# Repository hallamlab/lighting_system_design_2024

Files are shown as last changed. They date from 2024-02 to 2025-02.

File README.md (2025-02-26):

# An Automated High-Throughput Lighting System for Screening Photosynthetic Microorganisms in Plate-Based Formats

## Authors
Avery J. C. Noonan<sup>1,4,7</sup>, Paula M. N. Cameron<sup>2,4</sup>, Kalen Dofher<sup>2,4</sup>, Nannaphat Sukkasam<sup>2,4,5</sup>, Tony Liu<sup>3,4</sup>, Lucas Rönn<sup>2</sup>, Tanakarn Monshupanee<sup>5</sup>, and Steven J. Hallam<sup>1,2,3,4,6,7*</sup>

## Abstract
The capacity of photosynthetic microorganisms to fix carbon dioxide into biomass positions them as promising cell factories for industrial bioproduction with reduced environmental impact. However, limitations in screening throughput hinder the identification of enzymes, strains, and growth conditions needed to realize this potential. Here we present a microplate-based high-throughput cultivation system that can be integrated into existing automation infrastructure and supports growth of both prokaryotic and eukaryotic photosynthetic microorganisms. In one application, we optimize BG-11 medium compositions for *Synechococcus elongatus* UTEX 2973, *Chlamydomonas reinhardtii* UTEX 90, and *Nostoc hatei* CUBC1040, resulting in growth rate increases of 38.4% to 61.6%. In another application, we identify small molecules that influence growth rates in *Synechococcus elongatus* UTEX 2973, including candidate compounds for growth rate increase and dozens that prevent growth. The sensitivity, throughput, and extensibility of this system support screening, strain isolation, and growth optimization needed for the development of photosynthetic microbial cell factories.

---

## Repository Contents
The following table shows the contents of the repository and a brief description of each file:

| File | Topic | Directory | Description |
|---|---|---|---|
| **Noonan_HTP_lighting_system_figures.Rmd** | RMarkdown | . | RMarkdown generating all data figures |
| **Noonan_BG11-RSM_JMP_data_processing.Rmd** | RMarkdown | . | RMarkdown for RSM data reformatting for input into JMP |
| **PHERAstar_2x2_data_processing.py** | Python | . | Script for processing PHERAstar 2x2 data |
| **PHERAstar_standard_data_processing.py** | Python | . | Script for processing standard PHERAstar data |
| **varioskan_data_parsing.py** | Python | . | Script for parsing Varioskan data |
| **LED_driver.ino** | Arduino | . | Arduino script for controlling LED intensity |
| **parts-list.csv** | System | system-design/ | Parts list |
| **2973_plate-type_growth_data.csv** | Design / Validation | data/system-design/ | Culture OD data |
| **2973_seal_growth_data.csv** | Design / Validation | data/system-design/ | Culture OD data |
| **2973_spectrum_growth_data.csv** | Design / Validation | data/system-design/ | Culture OD data |
| **photodiode_array_data.csv** | Design / Validation | data/system-design/ | Photodiode data |
| **sensor_array_data.csv** | Design / Validation | data/system-design/ | Photodiode data |
| **layout_info.csv** | Design / Validation | data/system-design/ | Plate layout info |
| **echo_evaporation_data.csv** | Design / Validation | data/system-design/ | Evaporation data |
| **2973_BG11_growth_data.csv** | Primary Use-Cases | data/use-cases/primary/ | Culture OD data |
| **2973_BG11_plate_layout.csv** | Primary Use-Cases | data/use-cases/primary/ | Plate layout info |
| **2973_BG11_plate_metadata.csv** | Primary Use-Cases | data/use-cases/primary/ | Culture metadata |
| **antibiotics_growth_data.csv** | Primary Use-Cases | data/use-cases/primary/ | Culture OD data |
| **antiobiotics_plate_layout.csv** | Primary Use-Cases | data/use-cases/primary/ | Plate layout info |
| **antiobiotics_plate_metadata.csv** | Primary Use-Cases | data/use-cases/primary/ | Culture metadata |
| **layout_info.csv** | Primary Use-Cases | data/use-cases/primary/ | Plate layout info |
| **BG11_JMP_layout.csv** | BG-11 RSM | data/use-cases/BG11-RSM/ | Plate layout info |
| **BG11_opt_OD_data.csv** | BG-11 RSM | data/use-cases/BG11-RSM/ | Culture OD data |
| **flask_biomass_data_100uM.csv** | BG-11 RSM | data/use-cases/BG11-RSM/ | Culture biomass data |
| **bioactive_library_info.csv** | Bioactive Screen | data/use-cases/bioactive-screening/ | Screening library information |
| **bioactive_screen1_OD_data.csv** | Bioactive Screen | data/use-cases/bioactive-screening/ | Culture OD data |
| **bioactive_round2_OD_data.csv** | Bioactive Screen | data/use-cases/bioactive-screening/ | Culture OD data |
| **bioactive_screen_round2_hit_compound_info.csv** | Bioactive Screen | data/use-cases/bioactive-screening/ | Compound metadata |
| **bioactive_screen_round3_layout.csv** | Bioactive Screen | data/use-cases/bioactive-screening/ | Plate layout info |
| **bioactive_screen_round3_OD_data.csv** | Bioactive Screen | data/use-cases/bioactive-screening/ | Culture OD data |
| **bioactive_gradient_data.csv** | Bioactive Screen | data/use-cases/bioactive-screening/ | Culture OD data |
| **gossypetin_scan_data.csv** | Bioactive Screen | data/use-cases/bioactive-screening/ | Culture OD data |
| **layout_info.csv** | Bioactive Screen | data/use-cases/bioactive-screening/ | Plate layout info |
| **slipring_connector.stl** | Design / Validation | 3D model (.stl) | Model of slipring connector |
| **LED_array_support.stl** | Design / Validation | 3D model (.stl) | Model of LED array support structure |

---

## How to Cite
Please cite this repository and associated publication as follows:
> Noonan, A.J.C., Cameron, P.M.N., Dofher, K., Sukkasam, N., Liu, T., Rönn, L., Monshupanee, T., and Hallam, S.J. (2025). An automated high-throughput lighting system for screening photosynthetic microorganisms in plate-based formats.

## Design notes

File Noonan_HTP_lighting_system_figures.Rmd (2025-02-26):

---
title: "An automated high-throughput lighting-system for screening photosynthetic microorganisms in plate-based formats"
author: "Avery J. C. Noonan, Paula M. N. Cameron, Kalen Dofher, Nannaphat Sukkasam, Tony Liu, Tanakarn Monshupanee, and Steven J. Hallam"
date: "`r format(Sys.time(), '%A %d %B %Y')`"
output:
  html_document: default
  pdf_document: default
---

```{r setup, include=FALSE}
library(tidyverse)
library(lubridate)
library(kableExtra)
library(cowplot)
library(moments)
library(scales)
library(ggh4x)
library(RColorBrewer)
library(effsize)

knitr::opts_chunk$set(echo = FALSE, message = FALSE, warning = FALSE)
knitr::opts_knit$set(root.dir = '.')
```

## Protein Economy Modelling

Related figures:

  - Supplementary Figure 6

```{r protein_economy_model}
prots <- c("lhc", "pset", "lpb", "cbm", "rib", "mai")
mets <- c('hvi', 'atp', 'nadph', 'pre', 'lip')
mems <- c("thy", "cpm")

model_data_import <- read_csv("data/system-design/protein_economy_steady_state_output.csv") %>%
  select(-c(rep, X1)) %>%
  group_by(time, hv) %>%
  summarise_if(is.numeric, mean, na.rm = TRUE) %>%
  filter(time != 0) %>%
  pivot_longer(-c(time, hv, mu, bm, c_hvi), names_to = "component", values_to = "concentration") %>%
  separate(component, c("variable", "component")) %>%
  filter(hv >= 2) %>%
  ungroup() %>%
  mutate(mu_rel = mu/max(mu)*100) %>%
  group_by(variable, component) %>%
  mutate(comp_name = case_when(component == "lhc" ~ "Light harvesting complex",
                               component == "pset" ~ "Photosynthesis and electron transport",
                               component == "cbm" ~ "Carbon metabolism",
                               component == "rib" ~ "Ribosome",
                               component == "lpb" ~ "Lipid biosynthesis and membrane components",
                               component == "mai" ~ "Maintenance",
                               component == "atp" ~ "ATP",
                               component == "nadph" ~ "NADPH",
                               component == "pre" ~ "Precursors",
                               component == "lip" ~ "Lipids",
                               component == "cpm" ~ "Cytoplasmic membrane",
                               component == "thy" ~ "Thylakoid membrane"),
         comp_type = case_when(component %in% prots ~ "Proteins",
                               component %in% mets ~ "Metabolites",
                               component %in% mems ~ "Membranes"),
         comp_order = case_when(comp_type == "Proteins" ~ 1,
                               comp_type == "Metabolites" ~ 2,
                               comp_type == "Membranes" ~ 3)) %>%
  mutate(light = hv/100*1000)

conc_2 <- model_data_import %>%
  filter(hv == 2) %>%
  select(component, variable, concentration) %>%
  rename(conc_2 = concentration)

model_data <- model_data_import %>%
  filter(variable == "c") %>%
  left_join(conc_2, by = c("component", "variable")) %>%
  mutate(conc_rel = concentration/conc_2) %>%
  group_by(component, variable) %>%
  arrange(mu) %>%
  mutate(index = row_number())

model_delta_data <- model_data %>%
  select(component, variable, index, concentration) %>%
  mutate(index = index+1) %>%
  rename(conc_minus = concentration)

mu_100  <- model_data %>%
  filter(hv == 10) %>%
  ungroup() %>%
  select(mu, mu_rel) %>%
  distinct()

mu_plot <- model_data %>%
  ggplot(aes(x = light, y = mu)) +
  geom_line(linewidth = 1.5) +
  geom_hline(aes(yintercept = mu_100$mu), linetype = "dashed") +
  labs(x = expression(paste("Light Intensity (", mu,"mol/", "m"^2 ,"/s)")), y = expression(paste("Growth rate (", mu," [", "h"^-1, "])")))

supp_6a <- mu_plot +
  geom_text(data = mu_100, aes(0,mu,label = round(mu, 3)), vjust = -0.5, hjust = 0, size = 3, fontface = "plain", family = "sans", label.size = NA)
supp_6a

mu_rel_plot <- model_data %>%
  ggplot(aes(x = light, y = mu_rel)) +
  geom_line(linewidth = 1.5) +
  geom_hline(aes(yintercept = mu_100$mu_rel), linetype = "dashed") +
  labs(x = expression(paste("Light Intensity (", mu,"mol/", "m"^2 ,"/s)")), y = expression(paste("Relative growth rate (", mu[i],"/", mu[max]," x100)")))

supp_6b <- mu_rel_plot +
  geom_text(data = mu_100, aes(0,mu_rel,label = round(mu_rel, 2)), vjust = -0.5, hjust = 0, size = 3, fontface = "plain", family = "sans", label.size = NA)
supp_6b

components_legend <- cowplot::get_legend(model_data %>%
  filter(variable == "c") %>%
  ggplot(aes(x = light, y = conc_rel, colour = reorder(comp_name, comp_order))) +
  geom_line(linewidth = 1.5) +
  scale_y_log10() +
  facet_grid(cols = vars(reorder(comp_type, comp_order))) +
  labs(x = expression(paste("Light Intensity (", mu,"mol/", "m"^2 ,"/s)")), y = "Relative concentration", colour = "Biomass\nComponent"))

supp_6c <- model_data %>%
  filter(variable == "c") %>%
  ggplot(aes(x = light, y = conc_rel, colour = reorder(comp_name, comp_order))) +
  geom_line(linewidth = 1.5, show.legend = F) +
  geom_vline(aes(xintercept = 100), linetype = "dashed") +
  scale_y_log10() +
  facet_grid(cols = vars(reorder(comp_type, comp_order))) +
  labs(x = expression(paste("Light Intensity (", mu,"mol/", "m"^2 ,"/s)")), y = "Relative concentration", colour = "Biomass\nComponent")
supp_6c

supp_6d <- model_data %>%
  filter(variable == "c") %>%
  ggplot(aes(x = mu_rel, y = conc_rel, colour = reorder(comp_name, comp_order))) +
  geom_line(linewidth = 1.5, show.legend = F) +
  geom_vline(aes(xintercept = mu_100$mu_rel), linetype = "dashed") +
  scale_y_log10() +
  facet_grid(cols = vars(reorder(comp_type, comp_order))) +
  labs(x = expression(paste("Relative growth rate (", mu[i],"/", mu[max]," x100)")), y = "Relative concentration", colour = "Biomass\nComponent")
supp_6d

supp_6e <- model_data %>%
  left_join(model_delta_data, by = c('component', 'variable', 'index')) %>%
  mutate(conc_rel_delta = ((concentration-conc_minus)/conc_minus)) %>%
  filter(variable == "c") %>%
  ggplot(aes(x = light, y = conc_rel_delta, colour = reorder(comp_name, comp_order))) +
  geom_line(linewidth = 1.5, show.legend = F) +
  geom_vline(aes(xintercept = 100), linetype = "dashed") +
  # scale_y_log10() +
  facet_grid(cols = vars(reorder(comp_type, comp_order)), scales = "free_y") +
  labs(x = expression(paste("Light Intensity (", mu,"mol/", "m"^2 ,"/s)")), y = "Delta relative concentration", colour = "Biomass\nComponent")
supp_6e

supp_6f <- model_data %>%
  left_join(model_delta_data, by = c('component', 'variable', 'index')) %>%
  mutate(conc_rel_delta = ((concentration-conc_minus)/conc_minus)) %>%
  filter(variable == "c") %>%
  ggplot(aes(x = mu_rel, y = conc_rel_delta, colour = reorder(comp_name, comp_order))) +
  geom_line(linewidth = 1.5, show.legend = F) +
  geom_vline(aes(xintercept = mu_100$mu_rel), linetype = "dashed") +
  # scale_y_log10() +
  facet_grid(cols = vars(reorder(comp_type, comp_order)), scales = "free_y") +
  labs(x = expression(paste("Relative growth rate (", mu[i],"/", mu[max]," x100)")), y = "Delta relative concentration", colour = "Biomass\nComponent")
supp_6f
```

```{r model_plots}
mu_light_plots <- plot_grid(supp_6a, supp_6b,
                            labels = c('A', 'B'),
                            label_size = 14,
                            ncol = 2,
                            rel_widths = c(1, 1))

rel_conc_plots <- plot_grid(supp_6c, supp_6d,
          labels = c('C', 'D'), 
          label_size = 14, 
          ncol = 2,
          rel_widths = c(1, 1))

delta_conc_plots <- plot_grid(supp_6e, supp_6f,
          labels = c('E', 'F'), 
          label_size = 14, 
          ncol = 2,
          rel_widths = c(1, 1))

model_plots <- plot_grid(mu_light_plots, rel_conc_plots, delta_conc_plots,
          labels = c('', '', ''), 
          label_size = 14, 
          ncol = 1,
          rel_heights = c(1, 1, 1))

model_legend <- plot_grid(NULL, components_legend, NULL,
                          labels = c('', '', ''),
                          ncol = 1,
                          rel_heights = c(3,2,1))

supp6 <- plot_grid(model_plots, model_legend,
                          labels = c('', ''),
                          ncol = 2,
                          rel_widths = c(3, 1))
supp6
```

## LED Array - Light-Temperature Relationship

Related figures:

  - Supplementary Figure 16
  - Supplementary Figure 17A

```{r array_data_import}
array_data <- read_csv("data/system-design/sensor_array_data.csv")
```

### Temp Data Processing

```{r temp_plots}
t0_temp <- array_data %>%
  filter(type == "Temperature") %>%
  filter(Time == min(Time)) %>%
  group_by(material, current, position) %>%
  mutate(t0_temp = median(value)) %>%
  mutate(temp_norm = t0_temp-value) %>%
  select(current, position, material, replicate, temp_norm)

temp_array_data <- array_data %>%
  filter(type == "Temperature") %>%
  right_join(t0_temp, by = c('current', 'material', 'replicate', "position")) %>%
  mutate(value = value+temp_norm) %>%
  group_by(material, current) %>%
  mutate(max = max(Time)) %>%
  ungroup() %>%
  group_by(current) %>%
  mutate(max = min(max)) %>%
  filter(Time <= max) %>%
  mutate(time_group = ceiling(Time/600)) %>%
  group_by(current, material, sensor, time_group) %>%
  mutate(median = median(value)) %>%
  mutate(filter = case_when(Time == 52 ~ "No",
                            Time == 104 ~ "No",
                            value >= median*0.9 ~ "No",
                            value < median*0.9 ~ "Yes")) %>%
  filter(filter == "No") %>%
  ungroup() %>%
  select(-c(median, time_group, filter))

supp_16a <- temp_array_data %>% 
  filter(position == "plate") %>%
  filter(!(current == "70A" & replicate == "Plate 2" & material == "Copper")) %>%
  mutate(sensor = str_replace(sensor, "plate_temp_", "Plate #")) %>%
  ggplot(aes(x=Time/60, y=value, color = sensor, group = sensor)) +
  labs(y = 'Temperature', x = 'Time (minutes)', title = "LED Array Temperature (0-16 hours)", color = "Plate") +
  geom_line()+
  geom_point(shape=19, size=1) +
  facet_grid(rows = vars(material), cols = vars(current), scales = "free")
supp_16a

temp_sd <- temp_array_data %>%
  filter(position == "plate") %>%
  filter(Time > 30*60) %>%
  group_by(material, current, position, sensor) %>%
  summarise(sd = sd(value), mean = mean(value)) %>%
  group_by(material, current) %>%
  summarise(sd = mean(sd), mean = mean(mean))
temp_sd

temp_sd_under <- temp_array_data %>%
  filter(position == "under") %>%
  filter(Time > 30*60) %>%
  group_by(material, current, position, sensor) %>%
  summarise(sd = sd(value), mean = mean(value)) %>%
  group_by(material, current) %>%
  summarise(sd = mean(sd), mean = mean(mean))
temp_sd_under

temp_array_stat_data <- temp_array_data %>%
  filter(Time > 30*60)

plate_70A_f.test <- var.test(value ~ material, data = temp_array_stat_data %>% filter(position == "plate", current == "70A"))
plate_70A_f.test

plate_10A_f.test <- var.test(value ~ material, data = temp_array_stat_data %>% filter(position == "plate", current == "10A"))
plate_10A_f.test
```

### Light Data Processing

```{r light_plots}
t0_light <- array_data %>%
  filter(type == "Light") %>%
  filter(Time == min(Time)) %>%
  group_by(material, current, position) %>%
  mutate(t0_light = median(value)) %>%
  mutate(light_norm = t0_light-value) %>%
  select(current, position, material, replicate, light_norm)

light_array_data <- array_data %>%
  filter(type == "Light") %>%
  right_join(t0_light, by = c('current', 'material', 'replicate', "position")) %>%
  group_by(material, current) %>%
  mutate(max = max(Time)) %>%
  ungroup() %>%
  group_by(current) %>%
  mutate(max = min(max)) %>%
  filter(Time <= max) %>%
  mutate(time_group = ceiling(Time/600)) %>%
  group_by(current, material, sensor, time_group) %>%
  mutate(median = median(value)) %>%
  mutate(filter = case_when(Time == 52 ~ "No",
                            Time == 104 ~ "No",
                            value < 20 ~ "Yes",
                            value >= median*0.9 ~ "No",
                            value < median*0.9 ~ "Yes")) %>%
  filter(filter == "No") %>%
  ungroup() %>%
  select(-c(median, time_group, filter))

supp_16b <- light_array_data %>% 
  mutate(position = case_when(position == "edge" ~ "Edge",
                              position == "center" ~ "Center")) %>%
  filter(position != "ambient") %>%
  ggplot(aes(x=Time/60, y=value, color = position, group = sensor)) +
  labs(y = expression(paste("Light Intensity (", mu,"mol/", "m"^2 ,"/s)")), x = 'Time (minutes)', title = "LED Array Light Intensity (0-16 hours)", color = "Photodiode\nPosition") +
  geom_line()+
  geom_point(shape=19, size=1) +
  facet_grid(rows = vars(material), cols = vars(current), scales = "free")
supp_16b

lighting_sd <- light_array_data %>%
  filter(position != "ambient") %>%
  filter(Time > 30*60) %>%
  group_by(material, current, position, sensor) %>%
  summarise(sd = sd(value)) %>%
  group_by(material, current, position) %>%
  summarise(sd = mean(sd)) %>%
  pivot_wider(names_from = material, values_from = sd) %>%
  mutate(fold_increase = Copper/Aluminium)
lighting_sd

light_array_stat_data <- light_array_data %>%
  filter(position != "ambient") %>%
  filter(Time > 30*60)

center_70A_f.test <- var.test(value ~ material, data = light_array_stat_data %>% filter(position == "center", current == "70A"))
center_70A_f.test

center_10A_f.test <- var.test(value ~ material, data = light_array_stat_data %>% filter(position == "center", current == "10A"))
center_10A_f.test
```

```{r supp_array}
supp16 <- plot_grid(supp_16a, supp_16b,
          labels = c('A', 'B'), 
          label_size = 14, 
          ncol = 1,
          rel_heights = c(1, 1))
supp16
```

### Light - Temperature Relationship

```{r light_temp_plots}
combined_array_data <- bind_rows(light_array_data, temp_array_data)

supp17a <- combined_array_data %>%
  filter(Time > 105) %>%
  filter(position == "center" | position == "plate") %>%
  filter(!(current == "70A" & replicate == "Plate 2" & material == "Copper")) %>%
  select(-c(sensor, position, light_norm, temp_norm)) %>%
  pivot_wider(names_from = type, values_from = value) %>%
  ggplot(aes(x=Temperature, y=Light, colour = replicate)) +
  labs(y = expression(paste("Light Intensity (", mu,"mol/", "m"^2 ,"/s)")), x = 'Temperature (C)', colour = "Plate") +
  geom_point(shape=19, size=1) +
  facet_grid(rows = vars(current), cols = vars(material), scales = "free_y") +
  theme(legend.position="bottom")
supp17a
```

\newpage

## LED Array - Light Spectrum Testing

Related figures:

  - Supplementary Figure 17B
  - Supplementary Figure 19

```{r spectrum_data_import}
spectrum_growth_data <- read_csv('data/system-design/2973_spectrum_growth_data.csv') %>%
  mutate(Time = dmy_hms(Time), Timepoint = factor(Timepoint, levels = c('T0', 'T1', 'T2', 'T3', 'T4', 'T5', 'T6', 'T7', 'T8', 'T9', 'T10', 'T11', 'T12', 'T13', 'T14', 'T15', 'T16', 'T17'))) %>%
  pivot_longer(-c(Timepoint, Time, Wavelength, Plate, Row), names_to = 'Column', values_to = 'OD') %>%
  mutate(Column = as.numeric(Column)) %>%
  filter(!is.na(Wavelength))
```

```{r spectrum_plots}
supp17b <- spectrum_growth_data %>%
  filter(Timepoint != "T0",
         Timepoint != "T10",
         Timepoint != "T9",
         Timepoint != "T8") %>%
  mutate(case_when(Timepoint == "T1" ~ "T0",
                   Timepoint == "T2" ~ "T1",
                   Timepoint == "T3" ~ "T2",
                   Timepoint == "T4" ~ "T3",
                   Timepoint == "T5" ~ "T4",
                   Timepoint == "T6" ~ "T5")) %>%
  ggplot(aes(x=Timepoint, y=OD, fill = Plate)) +
  geom_boxplot() +
  labs(y = bquote(OD[750]), fill = "LED Spectrum")
supp17b

supp19 <- spectrum_growth_data %>%
  filter(Timepoint == 'T6', Wavelength == '750nm') %>%
  ggplot(aes(x=Column, y = reorder(Row, desc(Row)), fill = OD)) +
  geom_tile() +
  labs(y = '', x = '', title = "UTEX2973 by LED Array Spectrum (T6)", fill = bquote(OD[750])) +
  facet_grid(rows = vars(Plate))
supp19
```

```{r spectrum_calcs}
# ANOVA for each timepoint
T1_aov <- aov(OD ~ Plate, data = spectrum_growth_data %>% 
              filter(Timepoint == "T1", Wavelength == "750nm"))
T1_aov
T2_aov <- aov(OD ~ Plate, data = spectrum_growth_data %>% 
              filter(Timepoint == "T2", Wavelength == "750nm"))
T2_aov
T3_aov <- aov(OD ~ Plate, data = spectrum_growth_data %>% 
              filter(Timepoint == "T3", Wavelength == "750nm"))
T3_aov
T4_aov <- aov(OD ~ Plate, data = spectrum_growth_data %>% 
              filter(Timepoint == "T4", Wavelength == "750nm"))
T4_aov
T5_aov <- aov(OD ~ Plate, data = spectrum_growth_data %>% 
              filter(Timepoint == "T5", Wavelength == "750nm"))
T5_aov
T6_aov <- aov(OD ~ Plate, data = spectrum_growth_data %>% 
              filter(Timepoint == "T6", Wavelength == "750nm"))
T6_aov

# Tukey tests
T1_tukey <- data.frame(TukeyHSD(T1_aov, conf.level = 0.95)$Plate) %>%
  mutate(timepoint = "T1") %>%
  filter(p.adj <= 0.05) %>%
  rownames_to_column(var = "comparison")
T1_tukey

T2_tukey <- data.frame(TukeyHSD(T2_aov, conf.level = 0.95)$Plate) %>%
  mutate(timepoint = "T2") %>%
  filter(p.adj <= 0.05) %>%
  rownames_to_column(var = "comparison")
T2_tukey

T3_tukey <- data.frame(TukeyHSD(T3_aov, conf.level = 0.95)$Plate) %>%
  mutate(timepoint = "T3") %>%
  filter(p.adj <= 0.05) %>%
  rownames_to_column(var = "comparison")
T3_tukey

T4_tukey <- data.frame(TukeyHSD(T4_aov, conf.level = 0.95)$Plate) %>%
  mutate(timepoint = "T4") %>%
  filter(p.adj <= 0.05) %>%
  rownames_to_column(var = "comparison")
T4_tukey

T5_tukey <- data.frame(TukeyHSD(T5_aov, conf.level = 0.95)$Plate) %>%
  mutate(timepoint = "T5") %>%
  filter(p.adj <= 0.05) %>%
  rownames_to_column(var = "comparison")
T5_tukey

T6_tukey <- data.frame(TukeyHSD(T6_aov, conf.level = 0.95)$Plate) %>%
  mutate(timepoint = "T6") %>%
  filter(p.adj <= 0.05) %>%
  rownames_to_column(var = "comparison")
T6_tukey

# Combine all Tukey results
tukey_data <- bind_rows(T1_tukey, T2_tukey, T3_tukey, T4_tukey, T5_tukey, T6_tukey)

# Create summary table
tukey_data_table <- tukey_data %>%
  select(timepoint, comparison, p.adj)

# For effect size, we can use the effectsize package
eta_T6 <- eta_squared(T6_aov)
eta_T6

# View results
kable(tukey_data_table)
summary(T6_aov)
eta_T6
```

\newpage

## Cultivation Setup

### Plate Seal

Related figures:

  - Supplementary Figure 17C
  - Supplementary Figure 20

```{r seal_data_import}
seal_growth_data <- read_csv('data/system-design/2973_seal_growth_data.csv') %>%
  mutate(Time = dmy_hms(Time), Timepoint = factor(Timepoint, levels = c('T0', 'T1', 'T2', 'T3', 'T4', 'T5', 'T6', 'T7', 'T8', 'T9', 'T10', 'T11', 'T12', 'T13', 'T14', 'T15', 'T16', 'T17'))) %>%
  pivot_longer(-c(Timepoint, Time, Wavelength, Plate, Row), names_to = 'Column', values_to = 'OD') %>%
  mutate(Column = as.numeric(Column)) %>%
  filter(!is.na(Wavelength)) %>%
  filter(Timepoint != "T6")
```

```{r seal_plots}
supp17c <- seal_growth_data %>%
  ggplot(aes(x=Timepoint, y=OD, fill = Plate)) +
  geom_boxplot() +
  labs(y = bquote(OD[750]), fill = "Plate Seal")
supp17c

supp20 <- seal_growth_data %>%
  filter(Timepoint == 'T3', Wavelength == '750nm') %>%
  ggplot(aes(x=Column, y = reorder(Row, desc(Row)), fill = OD)) +
  geom_tile() +
  labs(y = '', x = '', title = "UTEX2973 by Plate Seal (T3)", fill = bquote(OD[750])) +
  facet_grid(rows = vars(Plate))
supp20
```

```{r seal_types_calcs}
# ANOVA for each timepoint
T1_seal_aov <- aov(OD ~ Plate, data = seal_growth_data %>% 
                   filter(Timepoint == "T1", Wavelength == "750nm"))
T1_seal_aov
T2_seal_aov <- aov(OD ~ Plate, data = seal_growth_data %>% 
                   filter(Timepoint == "T2", Wavelength == "750nm"))
T2_seal_aov
T3_seal_aov <- aov(OD ~ Plate, data = seal_growth_data %>% 
                   filter(Timepoint == "T3", Wavelength == "750nm"))
T3_seal_aov
T4_seal_aov <- aov(OD ~ Plate, data = seal_growth_data %>% 
                   filter(Timepoint == "T4", Wavelength == "750nm"))
T4_seal_aov

# Tukey tests
T1_seal_tukey <- data.frame(TukeyHSD(T1_seal_aov, conf.level = 0.95)$Plate) %>%
  mutate(timepoint = "T1") %>%
  filter(p.adj <= 0.05) %>%
  rownames_to_column(var = "comparison")

T2_seal_tukey <- data.frame(TukeyHSD(T2_seal_aov, conf.level = 0.95)$Plate) %>%
  mutate(timepoint = "T2") %>%
  filter(p.adj <= 0.05) %>%
  rownames_to_column(var = "comparison")

T3_seal_tukey <- data.frame(TukeyHSD(T3_seal_aov, conf.level = 0.95)$Plate) %>%
  mutate(timepoint = "T3") %>%
  filter(p.adj <= 0.05) %>%
  rownames_to_column(var = "comparison")
T3_seal_tukey

T4_seal_tukey <- data.frame(TukeyHSD(T4_seal_aov, conf.level = 0.95)$Plate) %>%
  mutate(timepoint = "T4") %>%
  filter(p.adj <= 0.05) %>%
  rownames_to_column(var = "comparison")

# Combine all Tukey results
seal_tukey_data <- bind_rows(T1_seal_tukey, T2_seal_tukey, T3_seal_tukey, 
                            T4_seal_tukey)

# Create summary table
seal_tukey_data_table <- seal_tukey_data %>%
  select(timepoint, comparison, p.adj)

# For effect size at T3 (since plot shows T3 data)
eta_T3_seal <- eta_squared(T3_seal_aov)

# View results
kable(seal_tukey_data_table)
summary(T3_seal_aov)
eta_T3_seal
```

```{r supp17}
supp17 <- plot_grid(supp17a, 
          plot_grid(supp17b, supp17c, 
                    ncol = 1, 
                    labels = c("B", "C"),
                    label_size = 14),
          labels = c('A', ''), 
          label_size = 14, 
          ncol = 2,
          rel_widths = c(3, 3))

supp17
```

### Evaporation Testing

Related figures:

  - Supplementary Figure 21
  - Supplementary Figure 22
  
```{r evaporation}
layout_info <- read_csv('data/system-design/layout_info.csv')

evaporation_data_import <- read_csv("data/system-design/echo_evaporation_data.csv")

evaporation_data <- evaporation_data_import %>%
  group_by(day, well, Column, Row, Seal, Culture) %>%
  summarise(volume = mean(volume, na.rm = TRUE)) %>%
  left_join(layout_info, by='well')

delta_table <- evaporation_data %>%
  group_by(day, Culture, Seal) %>%
  summarise(mean_volume = mean(volume, na.rm = TRUE)) %>%
  pivot_wider(names_from = day, values_from = mean_volume) %>%
  mutate(delta_vol_1 = `1`-`0`,
         delta_vol_2 = `2`-`0`,
         delta_vol_3 = `3`-`0`,
         delta_vol_4 = `4`-`0`) %>%
  select(Seal, Culture, delta_vol_1, delta_vol_2, delta_vol_3, delta_vol_4)
delta_table

evaporation_heatmap <- evaporation_data %>%
  filter(day %in% c(0, 4)) %>%
  pivot_wider(names_from = day, values_from = volume) %>%
  mutate(delta_vol = `4`-`0`) %>%
  filter(delta_vol <= 0) %>%
  mutate(Column_order = as.numeric(Column)) %>% #reorder columns to reflect how the plate looks
  ggplot(aes(x = reorder(Column, Column_order), y = reorder(Row, desc(Row)), fill = delta_vol)) +
  geom_tile() +
  labs(y = 'Row', x = 'Column', title = "Decrease in mean volume of plates from day 1 to day 5", fill = "Mean Change") +
  facet_grid(Seal ~ Culture, scales = "free") +
  theme(axis.text = element_text(size = 11), 
        axis.title = element_text(size = 12), 
        strip.text = element_text(size = 12))
evaporation_heatmap

supp21a <- evaporation_data %>%
  group_by(day, Culture, Seal) %>%
  summarise(sd_vol = sd(volume), mean_volume = mean(volume, na.rm = TRUE)) %>%
  ggplot(aes(x = day, y = mean_volume, group = interaction(Culture))) +
  geom_point(size=1) +
  geom_line(aes(linetype = "Mean Volume")) +
  geom_ribbon(aes(ymin = mean_volume - sd_vol, ymax = mean_volume + sd_vol, fill = "Standard Deviation"), alpha = 0.3) +
  labs(y = 'Mean Volume', x = 'Day') + 
  facet_grid(Seal ~ Culture, scales = "free") +
  theme(axis.text = element_text(size = 11), 
        axis.title = element_text(size = 12), 
        strip.text = element_text(size = 12)) +
  scale_x_continuous(limits = c(0, 4), labels = 0:4) +
  scale_y_continuous(limits = c(0, 100), breaks = c(0, 20, 40, 60, 80)) +
  scale_fill_manual(values = "red", labels = "Standard Deviation") +
  guides(linetype = guide_legend(title = "", override.aes = list(fill = "black")),
         fill = guide_legend(title = ""))
supp21a

supp21b <- evaporation_data %>%
  filter(Culture == 'Culture') %>%
  filter(day == 0 | day == 4) %>%
  mutate(day = paste('Day', day)) %>%
  ggplot(aes(x=Section, y=volume, group = Section)) +
  geom_boxplot(outlier.shape = NA, show.legend = FALSE) + 
  geom_jitter(aes(color = Section), show.legend = FALSE) +
  facet_grid(rows = vars(Seal), cols = vars(day)) +
  labs(x = 'Section', y = 'Well Volume') +
  theme(axis.text = element_text(size = 11), 
        axis.title = element_text(size = 12), 
        strip.text = element_text(size = 12))
supp21b
```

```{r supp17}
supp21 <- plot_grid(supp21a, supp21b, 
                    ncol = 1, 
                    labels = c("A", "B"),
                    label_size = 14,
                    align = 'v')

supp21
```

#### ANOVA / Tukey Comparing plate sections

```{r evaporation_stats_calcs}
library(effectsize)
stats_data <- evaporation_data

PermASeal_aov <- aov(volume ~ factor(Section), data = stats_data %>% filter(Seal == "PermASeal", day == 4))
summary(PermASeal_aov)

nunc_aov <- aov(volume ~ factor(Section), data = stats_data %>% filter(Seal == "Nunc Lid", day == 4))
summary(nunc_aov)

AeraSeal_aov <- aov(volume ~ factor(Section), data = stats_data %>% filter(Seal == "AeraSeal", day == 4))
summary(AeraSeal_aov)

BreatheEasy_aov <- aov(volume ~ factor(Section), data = stats_data %>% filter(Seal == "Breathe-Easy", day == 4))
summary(BreatheEasy_aov)

PermASeal_tukey <- data.frame(TukeyHSD(PermASeal_aov, conf.level = 0.95)$`factor(Section)`) %>%
  mutate(day = 4, Seal = "PermASeal") %>%
  filter(p.adj <= 0.05) %>%
  rownames_to_column(var = "comparison")
TukeyHSD(PermASeal_aov, conf.level = 0.95)$`factor(Section)`

nunc_tukey <- data.frame(TukeyHSD(nunc_aov, conf.level = 0.95)$`factor(Section)`) %>%
  mutate(day = 4, Seal = "Nunc Lid") %>%
  filter(p.adj <= 0.05) %>%
  rownames_to_column(var = "comparison")
TukeyHSD(nunc_aov, conf.level = 0.95)$`factor(Section)`

AeraSeal_tukey <- data.frame(TukeyHSD(AeraSeal_aov, conf.level = 0.95)$`factor(Section)`) %>%
  mutate(day = 4, Seal = "AeraSeal") %>%
  filter(p.adj <= 0.05) %>%
  rownames_to_column(var = "comparison")
TukeyHSD(AeraSeal_aov, conf.level = 0.95)$`factor(Section)`

BreatheEasy_tukey <- data.frame(TukeyHSD(BreatheEasy_aov, conf.level = 0.95)$`factor(Section)`) %>%
  mutate(day = 4, Seal = "Breathe-Easy") %>%
  filter(p.adj <= 0.05) %>%
  rownames_to_column(var = "comparison")
TukeyHSD(BreatheEasy_aov, conf.level = 0.95)$`factor(Section)`

tukey_data <- bind_rows(PermASeal_tukey, nunc_tukey, AeraSeal_tukey, BreatheEasy_tukey)

tukey_data_table <- tukey_data %>%
  select(Seal, day, comparison, p.adj)

kable(tukey_data)

cohens_f_perm <- cohens_f(PermASeal_aov)
cohens_f_perm
cohens_f_aera <- cohens_f(AeraSeal_aov)
cohens_f_aera
cohens_f_nunc <- cohens_f(nunc_aov)
cohens_f_nunc
cohens_f_breathe <- cohens_f(BreatheEasy_aov)
cohens_f_breathe
```

```{r evaporation_stats2}
PermASeal_aov <- aov(volume ~ factor(Section), data = stats_data %>% filter(Seal == "PermASeal", day == 3))
summary(PermASeal_aov)
nunc_aov <- aov(volume ~ factor(Section), data = stats_data %>% filter(Seal == "Nunc Lid", day == 3))
summary(nunc_aov)
AeraSeal_aov <- aov(volume ~ factor(Section), data = stats_data %>% filter(Seal == "AeraSeal", day == 3))
summary(AeraSeal_aov)
BreatheEasy_aov <- aov(volume ~ factor(Section), data = stats_data %>% filter(Seal == "Breathe-Easy", day == 3))
summary(BreatheEasy_aov)
PermASeal_tukey <- data.frame(TukeyHSD(PermASeal_aov, conf.level = 0.95)$`factor(Section)`) %>%
  mutate(day = 3, Seal = "PermASeal") %>%
  filter(p.adj <= 0.05) %>%
  rownames_to_column(var = "comparison")
TukeyHSD(PermASeal_aov, conf.level = 0.95)$`factor(Section)`
nunc_tukey <- data.frame(TukeyHSD(nunc_aov, conf.level = 0.95)$`factor(Section)`) %>%
  mutate(day = 3, Seal = "Nunc Lid") %>%
  filter(p.adj <= 0.05) %>%
  rownames_to_column(var = "comparison")
TukeyHSD(nunc_aov, conf.level = 0.95)$`factor(Section)`
AeraSeal_tukey <- data.frame(TukeyHSD(AeraSeal_aov, conf.level = 0.95)$`factor(Section)`) %>%
  mutate(day = 3, Seal = "AeraSeal") %>%
  filter(p.adj <= 0.05) %>%
  rownames_to_column(var = "comparison")
TukeyHSD(AeraSeal_aov, conf.level = 0.95)$`factor(Section)`
BreatheEasy_tukey <- data.frame(TukeyHSD(BreatheEasy_aov, conf.level = 0.95)$`factor(Section)`) %>%
  mutate(day = 3, Seal = "Breathe-Easy") %>%
  filter(p.adj <= 0.05) %>%
  rownames_to_column(var = "comparison")
TukeyHSD(BreatheEasy_aov, conf.level = 0.95)$`factor(Section)`
tukey_data <- bind_rows(PermASeal_tukey, nunc_tukey, AeraSeal_tukey, BreatheEasy_tukey)
tukey_data_table <- tukey_data %>%
  select(Seal, day, comparison, p.adj)
kable(tukey_data)
cohens_f_perm <- cohens_f(PermASeal_aov)
cohens_f_perm
cohens_f_aera <- cohens_f(AeraSeal_aov)
cohens_f_aera
cohens_f_nunc <- cohens_f(nunc_aov)
cohens_f_nunc
cohens_f_breathe <- cohens_f(BreatheEasy_aov)
cohens_f_breathe
```

### Photodiode Array Evenness Testing

Related figures:

  - Supplementary Figure 22
  
```{r photodiode_even}
photo_data <- read_csv("data/system-design/photodiode_array_data.csv")

photo_data %>%
  group_by(distance, section) %>%
  summarise(value = median(value)) %>%
  pivot_wider(names_from = section, values_from = value) %>%
  mutate(delta = percent(1-(Outside / Inside), scale = 100))

med_lines <- photo_data %>%
  group_by(distance, section) %>%
  summarise(value = median(value)) %>%
  pivot_wider(names_from = section, values_from = value) %>%
  mutate(delta = Outside / Inside) %>%
  select(-c(Inside, Outside))

med_inside <- photo_data %>%
  group_by(distance, section) %>%
  summarise(value = median(value)) %>%
  pivot_wider(names_from = section, values_from = value) %>%
  select(distance, Inside)

min <- photo_data %>%
  group_by(distance, section, sensor) %>%
  summarise(value = median(value)) %>%
  group_by(distance, section) %>%
  summarise(value = min(value)) %>%
  pivot_wider(names_from = section, values_from = value) %>%
  select(-Inside) %>%
  left_join(med_inside, by = 'distance') %>%
  mutate(delta = Outside / Inside) %>%
  select(-c(Inside, Outside)) %>%
  mutate(set = "min")

max <- photo_data %>%
  group_by(distance, section, sensor) %>%
  summarise(value = median(value)) %>%
  group_by(distance, section) %>%
  summarise(value = max(value)) %>%
  pivot_wider(names_from = section, values_from = value) %>%
  select(-Inside) %>%
  left_join(med_inside, by = 'distance') %>%
  mutate(delta = Outside / Inside) %>%
  select(-c(Inside, Outside)) %>%
  mutate(set = "max")

range_data <- bind_rows(min, max) %>%
  mutate(pol_order = case_when(set == "max" ~ distance,
                               set == "min" ~ -1*distance)) %>%
  arrange(pol_order)

supp22a <- ggplot() +
  geom_polygon(data = range_data, mapping = aes(y = delta, x = distance), fill = "lightblue") + 
  geom_path(data = med_lines, mapping = aes(y = delta, x = distance), size = 1.5, color = "black") +
  geom_vline(xintercept = c(0.3, 2), linetype = "dashed") +
  labs(y = bquote("Relative intensity ("*I[OUT]*"/"*I[IN]*")"), x = "Distance (cm)") +
  ylim(0,1.01)

supp22c <-ggplot() +
  geom_polygon(data = range_data, mapping = aes(y = delta, x = distance), fill = "lightblue") + 
  geom_path(data = med_lines, mapping = aes(y = delta, x = distance), size = 1.5, color = "black") +
  geom_vline(xintercept = c(0.3, 2), linetype = "dashed") +
  labs(y = bquote("Relative intensity ("*I[OUT]*"/"*I[IN]*")"), x = "Distance (cm) [log2]") +
  ylim(0,1.01) +
  scale_x_continuous(trans='log2')

distance_means <- photo_data %>%
  group_by(distance) %>%
  summarise(mean = mean(value)) %>%
  select(distance, mean)

norm_sd <- photo_data %>%
  left_join(distance_means, by = 'distance') %>%
  mutate(value = value/mean)

norm_sd %>%
  group_by(distance) %>%
  summarise(value = sd(value))

supp22b <- norm_sd %>%
  group_by(distance) %>%
  summarise(value = sd(value)) %>%
  ggplot(aes(x = distance, y = value)) +
  geom_line(size = 1.5) +
  geom_vline(xintercept = c(0.3, 2), linetype = "dashed") +
  labs(y = "Standard deviation", x = "Distance (cm)")  +
  ylim(0, NA)

supp22d <- norm_sd %>%
  group_by(distance) %>%
  summarise(value = sd(value)) %>%
  ggplot(aes(x = distance, y = value)) +
  geom_line(size = 1.5) +
  geom_vline(xintercept = c(0.3, 2), linetype = "dashed") +
  labs(y = "Standard deviation", x = "Distance (cm) [log2]") +
  scale_x_continuous(trans='log2') +
  ylim(0, NA)

supp22ab <- plot_grid(supp22a, supp22b,
                                     ncol = 2, 
                                     labels = c("A", "B"),
                                     label_size = 14)

supp22cd <- plot_grid(supp22c, supp22d,
                                     ncol = 2, 
                                     labels = c("C", "D"),
                                     label_size = 14)

supp22 <- plot_grid(supp22ab, supp22cd,
          ncol = 1, 
          labels = c("", ""),
          label_size = 14)
supp22
```
  
### Plate Type Selection

Related figures:

  - Figure 2
  - Supplementary Figure 24
  - Supplementary Figure 25

```{r plate_type_import}
layout_info <- read_csv('data/system-design/layout_info.csv')

OD_data_distribution <- read_csv('data/system-design-mod/2973_plate-type_growth_data.csv') %>%
  mutate(time = ymd_hms(time), timepoint = factor(timepoint, levels = c('T0', 'T1', 'T2', 'T3', 'T4', 'T5', 'T6', 'T7', 'T8', 'T9', 'T10', 'T11', 'T12', 'T13', 'T14', 'T15', 'T16', 'T17', 'T18'))) %>%
  mutate(OD = as.numeric(OD)) %>%
  mutate(measurement_ID = paste(plate_ID, wavelength, sep = "_")) %>%
  mutate(value_ID = paste(measurement_ID, well, sep = ".")) %>%
  separate(well, into = c('row', 'column'), sep = 1, remove = FALSE) %>%
  separate(plate_ID, sep = "_", into = c('plate_type', 'replicate'), remove = F) %>%
  right_join(layout_info, by = 'well') %>%
  mutate(column = as.numeric(column))

t0_times <- OD_data_distribution %>%
  filter(timepoint == "T0") %>%
  ungroup() %>%
  group_by(plate_type, wavelength) %>%
  slice_min(order_by = time, n = 1) %>%
  select(c(time, plate_type, wavelength)) %>%
  distinct() %>%
  rename(T0_time = time)

run_times <- OD_data_distribution %>%
  ungroup() %>%
  group_by(timepoint, plate_type, wavelength) %>%
  slice_min(order_by = time, n = 1) %>%
  select(c(timepoint, time, plate_type, wavelength)) %>%
  distinct() %>%
  rename(run_time = time)

distribution_data <- OD_data_distribution %>%
  left_join(t0_times, by = c("plate_type", "wavelength")) %>%
  left_join(run_times, by = c("plate_type", "wavelength", "timepoint")) %>%
  mutate(delta_time = run_time - T0_time,
         hours = as.numeric(delta_time)/3600) %>%
  filter(timepoint != "T8")

distribution_data_calcs <- distribution_data %>%
  ungroup() %>%
  filter(wavelength == 750) %>%
  group_by(plate_type, timepoint, Section) %>%
  summarise(median_OD = median(OD)) %>%
  ungroup() %>%
  group_by(plate_type) %>%
  mutate(rel_OD = median_OD/max(median_OD)) %>%
  select(-c(median_OD)) %>%
  pivot_wider(names_from = timepoint, values_from = rel_OD)

distribution_data_calcs2 <- distribution_data %>%
  ungroup() %>%
  filter(wavelength == 750) %>%
  group_by(plate_type, timepoint) %>%
  summarise(median_OD = median(OD)) %>%
  pivot_wider(names_from = plate_type, values_from = median_OD) %>%
  mutate(delta = (1-clear/black)*100)

distribution_data_min_max <- distribution_data %>%
  group_by(plate_ID, plate_type, timepoint) %>%
  summarise(sd = sd(OD))

OD750_data <- distribution_data %>%
  filter(wavelength == 750)

t.test_T1 <- t.test(OD ~ plate_type, data = OD750_data %>% filter(timepoint == "T1"))
t.test_T1

t.test_T2 <- t.test(OD ~ plate_type, data = OD750_data %>% filter(timepoint == "T2"))
t.test_T2

t.test_T3 <- t.test(OD ~ plate_type, data = OD750_data %>% filter(timepoint == "T3"))
t.test_T3

t.test_T4 <- t.test(OD ~ plate_type, data = OD750_data %>% filter(timepoint == "T4"))
t.test_T4

t.test_T5 <- t.test(OD ~ plate_type, data = OD750_data %>% filter(timepoint == "T5"))
t.test_T5

t.test_T6 <- t.test(OD ~ plate_type, data = OD750_data %>% filter(timepoint == "T6"))
t.test_T6

t.test_T7 <- t.test(OD ~ plate_type, data = OD750_data %>% filter(timepoint == "T7"))
t.test_T7

# For each timepoint
t1_effect <- cohen.d(OD ~ plate_type, data = OD750_data %>% filter(timepoint == "T1"))
t1_effect
t2_effect <- cohen.d(OD ~ plate_type, data = OD750_data %>% filter(timepoint == "T2"))
t2_effect
t3_effect <- cohen.d(OD ~ plate_type, data = OD750_data %>% filter(timepoint == "T3"))
t3_effect
t4_effect <- cohen.d(OD ~ plate_type, data = OD750_data %>% filter(timepoint == "T4"))
t4_effect
t5_effect <- cohen.d(OD ~ plate_type, data = OD750_data %>% filter(timepoint == "T5"))
t5_effect
t6_effect <- cohen.d(OD ~ plate_type, data = OD750_data %>% filter(timepoint == "T6"))
t6_effect
t7_effect <- cohen.d(OD ~ plate_type, data = OD750_data %>% filter(timepoint == "T7"))
t7_effect
```

```{r plate_type_plots_OD750}
fig2b <- layout_info %>%
  separate(well, into = c('row', 'column'), sep = 1, remove = FALSE) %>%
  ggplot(aes(x=column, y = reorder(row, desc(row)), fill = Section)) +
  geom_tile(color = "grey") +
  labs(y = '', x = '', fill = "Plate\nSection") +
  theme(axis.text = element_blank(),
        legend.position="bottom")
fig2b

fig2a <- distribution_data %>%
  filter(wavelength == 750) %>%
  mutate(days = hours/24) %>%
  group_by(days, timepoint, plate_ID, plate_type) %>%
  summarise(OD = median(OD)) %>%
  ggplot(aes(x = days, y = OD, color = plate_type, group = plate_ID)) +
  geom_line(show.legend = F) +
  geom_point(show.legend = F) +
  labs(y = bquote(OD[750]), x = 'Days', colour = 'Plate type')
fig2a

fig2c <- distribution_data %>%
  filter(timepoint == "T3" | timepoint == "T5") %>%
  filter(wavelength == 750) %>%
  ggplot(aes(x=Section, y=OD, group = Section)) +
  geom_boxplot(outlier.shape = NA, show.legend = FALSE) + 
  geom_jitter(aes(color = Section), show.legend = FALSE) +
  facet_grid(rows = vars(plate_type), cols = vars(timepoint), scales = "free_y") +
  labs(x = 'Section', y = bquote(OD[750])) #, title = "OD750 distribution at T3 and T5"
fig2c

fig2d <- distribution_data %>%
  filter(timepoint == "T5") %>%
  filter(wavelength == 750) %>%
  ggplot(aes(x=OD, group = Section, fill = Section, colour = Section)) +
  geom_density(alpha = 0.2, show.legend = FALSE) + 
  facet_grid(cols = vars(plate_type), rows = vars(timepoint), scales = "free") +
  labs(y = 'Density', x = bquote(OD[750]))
fig2d

# Heatmaps

supp24 <- distribution_data %>%
  filter(timepoint == "T3", wavelength == 750) %>%
  filter(replicate == 1) %>%
  group_by(well, plate_type, wavelength, column, row, timepoint) %>%
  summarise(OD = mean(OD)) %>%
  ggplot(aes(x=column, y = reorder(row, desc(row)), fill = OD)) +
  geom_tile() +
  labs(y = '', x = '', title = "UTEX2973 by Plate Type (T3 / replicate #1)") +
  facet_grid(rows = vars(plate_type), cols = vars(timepoint), scales = "free_y")
supp24
```

```{r growth_rate_plots}
last_data <- distribution_data %>%
  filter(wavelength == 750) %>%
  select(plate_ID, timepoint, well, OD, hours) %>%
  filter(timepoint != "T8") %>%
  mutate(timepoint = case_when(timepoint == "T0" ~"T1",
                               timepoint == "T1" ~"T2",
                               timepoint == "T2" ~"T3",
                               timepoint == "T3" ~"T4",
                               timepoint == "T4" ~"T5",
                               timepoint == "T5" ~"T6",
                               timepoint == "T6" ~"T7",
                               timepoint == "T7" ~"T8")) %>%
  rename(last_OD = OD, last_hours = hours)

growth_rates_calcs <- distribution_data %>%
  filter(wavelength == 750) %>%
  filter(timepoint != "T0") %>%
  left_join(last_data, by = c('plate_ID', 'timepoint', 'well')) %>%
  mutate(delta_OD = (OD-last_OD)/last_OD, delta_hours = hours-last_hours) %>%
  mutate(growth_rate = delta_OD/delta_hours)
  
growth_rates <- growth_rates_calcs %>%
  group_by(hours, timepoint, plate_type, last_hours, Section) %>%
  summarise(growth_rate = median(growth_rate))

growth_rates_max_min <- growth_rates_calcs %>%
  mutate(growth_rate = as.numeric(growth_rate)) %>%
  ungroup() %>%
  group_by(timepoint, hours, plate_type) %>%
  summarise(median = median(growth_rate), mean = mean(growth_rate), max = max(growth_rate), n = n(), 
            devs = (growth_rate-mean)^2,
            var = sum(devs)/(n-1),
            sd = sqrt(var)) %>%
  select(-devs) %>%
  distinct()
growth_rates_max_min

growth_rates %>%
  ungroup() %>%
  group_by(plate_type, Section) %>%
  filter(growth_rate == max(growth_rate))

fig2_rates <- growth_rates_calcs %>%
  group_by(hours, timepoint, plate_type, plate_ID) %>%
  summarise(growth_rate = median(growth_rate)) %>%
  mutate(days = hours/24) %>%
  ggplot(aes(x = days, y = growth_rate, color = plate_type, group = plate_ID)) +
  geom_line(show.legend = F) +
  geom_point(show.legend = F) +
  labs(y = expression(paste("Growth rate (", mu," [", "h"^-1, "])")), x = 'Days', colour = 'Plate type')
fig2_rates

fig2_rates_legend <- cowplot::get_legend(growth_rates_calcs %>%
  group_by(hours, timepoint, plate_type, plate_ID) %>%
  summarise(growth_rate = median(growth_rate)) %>%
  mutate(days = hours/24) %>%
  ggplot(aes(x = days, y = growth_rate, color = plate_type, group = plate_ID)) +
  geom_line() +
  geom_point() +
  labs(colour = 'Plate Type'))
  
fig2_rates_sections <- growth_rates %>%
  mutate(days = hours/24) %>%
  group_by(days, timepoint, plate_type, Section) %>%
  summarise(growth_rate = median(growth_rate)) %>%
  ggplot(aes(x = days, y = growth_rate, color = Section, group = Section)) +
  geom_line() +
  geom_point() +
  labs(y = expression(paste("Growth rate (", mu," [", "h"^-1, "])")), 
       x = 'Days', 
       colour = 'Plate\nSection') +
  facet_wrap(~plate_type)
fig2_rates_sections

growth_rates_calcs %>%
  filter(timepoint == "T3" | timepoint == "T5") %>%
  ggplot(aes(x=Section, y=growth_rate, group = Section)) +
  geom_boxplot(outlier.shape = NA, show.legend = FALSE) + 
  geom_jitter(aes(color = Section), show.legend = FALSE) +
  facet_grid(rows = vars(plate_type), cols = vars(timepoint), scales = "free_y") +
  labs(x = 'Section', y = bquote(OD[750])) #, title = "OD750 distribution at T3 and T5"
```

```{r plate_type_plots_pigments}
rel_distribution_data <- distribution_data %>%
  ungroup() %>%
  group_by(timepoint, plate_type) %>%
  mutate(hours = min(hours)) %>%
  select(replicate, timepoint, wavelength, hours, plate_type, plate_ID, OD, well, Section, row, column) %>%
  pivot_wider(names_from = wavelength, values_from = OD) %>%
  mutate(OD750 = `750`) %>%
  pivot_longer(c(`444`, `750`, `495`, `634`, `684`), values_to = 'OD', names_to = 'wavelength') %>%
  filter(wavelength != 750) %>%
  mutate(OD = OD/OD750) %>%
  mutate(days = hours/24)

fig2e <- rel_distribution_data %>%
  group_by(days, timepoint, plate_ID, plate_type, wavelength) %>%
  summarise(OD = median(OD)) %>%
  filter(wavelength != 684) %>%
  mutate(wavelength_name = paste0("OD[", wavelength, "] / OD[750]")) %>%
  # mutate(wavelength_name = levels(wavelength_name, c("OD[444] / OD[750]","OD[495] / OD[750]", "OD[634] / OD[750]"))) %>%
  ggplot(aes(x = days, y = OD, color = plate_type, group = plate_ID)) +
  geom_line() +
  geom_point() +
  facet_grid(rows = vars(wavelength_name), scales = "free_y", labeller = label_parsed) +
  labs(y = "Relative OD", x = 'Days', colour = 'Plate type')
fig2e

fig2f <- rel_distribution_data %>%
  filter(timepoint == "T5") %>%
  filter(wavelength != 684) %>%
  mutate(wavelength_name = paste0("OD[", wavelength, "] / OD[750]")) %>%
  # filter(OD < 0.75) %>%
  ggplot(aes(x=Section, y=OD, group = Section)) +
  geom_boxplot(outlier.shape = NA, show.legend = FALSE) + 
  geom_jitter(aes(color = Section), show.legend = FALSE) +
  facet_grid(cols = vars(plate_type), rows = vars(wavelength_name), scales = "free_y", labeller = label_parsed) +
  labs(x = 'Section', y = "Relative OD")

fig2f

# Heatmaps
supp25 <- rel_distribution_data %>%
  filter(timepoint == "T3") %>%
  filter(replicate == 1) %>%
  mutate(wavelength_name = paste0("OD", wavelength, " / OD750")) %>%
  group_by(well, plate_type, wavelength_name, column, row) %>%
  summarise(OD = mean(OD)) %>%
  ggplot(aes(x=column, y = reorder(row, desc(row)), fill = OD)) +
  geom_tile() +
  labs(y = '', x = '', title = "Relative Photopigment Abs by Plate Type (T3)") +
  facet_grid(cols = vars(plate_type), rows = vars(wavelength_name), scales = "free_y")
supp25
```

```{r fig2}
fig2.1A <- plot_grid(fig2a, fig2_rates, fig2_rates_legend,
                    labels = c("A", "", ""),
                    ncol = 3,
                    label_size = 14,
                    rel_widths = c(3, 3, 1))

fig2.1 <- plot_grid(fig2.1A, fig2b,
                    labels = c("A", "B"),
                    ncol = 2,
                    label_size = 14,
                    rel_widths = c(5, 2))

fig2.2 <- plot_grid(fig2c, fig2d,
                    labels = c("C", "D"),
                    ncol = 2,
                    label_size = 14,
                    rel_widths = c(3, 3))

fig2.3 <- plot_grid(fig2e, fig2f,
                    labels = c("E", "F"),
                    ncol = 2,
                    label_size = 14,
                    rel_widths = c(3, 3))

fig2 <- plot_grid(fig2.1, fig2.2, fig2.3,
          ncol = 1,
          labels = c('', '', ''),
          label_size = 1,
          rel_heights = c(3, 3, 5))
fig2
```

\newpage

#### ANOVA / Tukey Comparing plate sections

```{r plate_type_plots_stats_calcs}
calculate_partial_eta_squared <- function(aov_model) {
  anova_table <- summary(aov_model)[[1]]
  ss_effect <- anova_table[1, "Sum Sq"]
  ss_total <- sum(anova_table[, "Sum Sq"])
  partial_eta_squared <- ss_effect / ss_total
  return(partial_eta_squared)
}

stats_data <- distribution_data %>%
  filter(wavelength == 750)

clear_aov_t2 <- aov(OD ~ factor(Section), data = stats_data %>% filter(plate_type == "clear", timepoint == "T2"))
summary(clear_aov_t2)
black_aov_t2 <- aov(OD ~ factor(Section), data = stats_data %>% filter(plate_type == "black", timepoint == "T2"))
summary(black_aov_t2)

clear_aov_t3 <- aov(OD ~ factor(Section), data = stats_data %>% filter(plate_type == "clear", timepoint == "T3"))
summary(clear_aov_t3)
black_aov_t3 <- aov(OD ~ factor(Section), data = stats_data %>% filter(plate_type == "black", timepoint == "T3"))
summary(black_aov_t3)

clear_aov_t4 <- aov(OD ~ factor(Section), data = stats_data %>% filter(plate_type == "clear", timepoint == "T4"))
summary(clear_aov_t4)
black_aov_t4 <- aov(OD ~ factor(Section), data = stats_data %>% filter(plate_type == "black", timepoint == "T4"))
summary(black_aov_t4)

clear_aov_t5 <- aov(OD ~ factor(Section), data = stats_data %>% filter(plate_type == "clear", timepoint == "T5"))
summary(clear_aov_t5)
black_aov_t5 <- aov(OD ~ factor(Section), data = stats_data %>% filter(plate_type == "black", timepoint == "T5"))
summary(black_aov_t5)

clear_aov_t6 <- aov(OD ~ factor(Section), data = stats_data %>% filter(plate_type == "clear", timepoint == "T6"))
summary(clear_aov_t6)
black_aov_t6 <- aov(OD ~ factor(Section), data = stats_data %>% filter(plate_type == "black", timepoint == "T6"))
summary(black_aov_t6)

# Clear plates
cohens_f_clear_t2 <- cohens_f(clear_aov_t2)
cohens_f_clear_t2
cohens_f_clear_t3 <- cohens_f(clear_aov_t3)
cohens_f_clear_t3
cohens_f_clear_t4 <- cohens_f(clear_aov_t4)
cohens_f_clear_t4
cohens_f_clear_t5 <- cohens_f(clear_aov_t5)
cohens_f_clear_t5
cohens_f_clear_t6 <- cohens_f(clear_aov_t6)
cohens_f_clear_t6

# Black plates
cohens_f_black_t2 <- cohens_f(black_aov_t2)
cohens_f_black_t2
cohens_f_black_t3 <- cohens_f(black_aov_t3)
cohens_f_black_t3
cohens_f_black_t4 <- cohens_f(black_aov_t4)
cohens_f_black_t4
cohens_f_black_t5 <- cohens_f(black_aov_t5)
cohens_f_black_t5
cohens_f_black_t6 <- cohens_f(black_aov_t6)
cohens_f_black_t6
```

```{r plate_type_plots_stats_summary_tukey}
calculate_cohens_d <- function(data, group_var, value_var, group1, group2) {
  group1_data <- data[data[[group_var]] == group1, ][[value_var]]
  group2_data <- data[data[[group_var]] == group2, ][[value_var]]
  
  n1 <- length(group1_data)
  n2 <- length(group2_data)
  
  mean_diff <- mean(group1_data) - mean(group2_data)
  pooled_sd <- sqrt(((n1 - 1) * var(group1_data) + (n2 - 1) * var(group2_data)) / (n1 + n2 - 2))
  
  cohens_d <- mean_diff / pooled_sd
  return(cohens_d)
}

clear_tukey_t2 <- data.frame(TukeyHSD(clear_aov_t3, conf.level = 0.95)$`factor(Section)`) %>%
  mutate(
    timepoint = "T2", 
    plate_type = "clear",
    cohens_d = sapply(rownames(.), function(comp) {
      groups <- strsplit(comp, "-")[[1]]
      calculate_cohens_d(
        stats_data %>% filter(plate_type == "clear", timepoint == "T2"),
        "Section", "OD", groups[1], groups[2]
      )
    })
  ) %>%
  filter(p.adj <= 0.05) %>%
  rownames_to_column(var = "comparison")

black_tukey_t2 <- data.frame(TukeyHSD(black_aov_t3, conf.level = 0.95)$`factor(Section)`) %>%
  mutate(
    timepoint = "T2", 
    plate_type = "black",
    cohens_d = sapply(rownames(.), function(comp) {
      groups <- strsplit(comp, "-")[[1]]
      calculate_cohens_d(
        stats_data %>% filter(plate_type == "black", timepoint == "T2"),
        "Section", "OD", groups[1], groups[2]
      )
    })
  ) %>%
  filter(p.adj <= 0.05) %>%
  rownames_to_column(var = "comparison")

# T3
clear_tukey_t3 <- data.frame(TukeyHSD(clear_aov_t3, conf.level = 0.95)$`factor(Section)`) %>%
  mutate(
    timepoint = "T3", 
    plate_type = "clear",
    cohens_d = sapply(rownames(.), function(comp) {
      groups <- strsplit(comp, "-")[[1]]
      calculate_cohens_d(
        stats_data %>% filter(plate_type == "clear", timepoint == "T3"),
        "Section", "OD", groups[1], groups[2]
      )
    })
  ) %>%
  filter(p.adj <= 0.05) %>%
  rownames_to_column(var = "comparison")

black_tukey_t3 <- data.frame(TukeyHSD(black_aov_t3, conf.level = 0.95)$`factor(Section)`) %>%
  mutate(
    timepoint = "T3", 
    plate_type = "black",
    cohens_d = sapply(rownames(.), function(comp) {
      groups <- strsplit(comp, "-")[[1]]
      calculate_cohens_d(
        stats_data %>% filter(plate_type == "black", timepoint == "T3"),
        "Section", "OD", groups[1], groups[2]
      )
    })
  ) %>%
  filter(p.adj <= 0.05) %>%
  rownames_to_column(var = "comparison")

# T4
clear_tukey_t4 <- data.frame(TukeyHSD(clear_aov_t4, conf.level = 0.95)$`factor(Section)`) %>%
  mutate(
    timepoint = "T4", 
    plate_type = "clear",
    cohens_d = sapply(rownames(.), function(comp) {
      groups <- strsplit(comp, "-")[[1]]
      calculate_cohens_d(
        stats_data %>% filter(plate_type == "clear", timepoint == "T4"),
        "Section", "OD", groups[1], groups[2]
      )
    })
  ) %>%
  filter(p.adj <= 0.05) %>%
  rownames_to_column(var = "comparison")

black_tukey_t4 <- data.frame(TukeyHSD(black_aov_t4, conf.level = 0.95)$`factor(Section)`) %>%
  mutate(
    timepoint = "T4", 
    plate_type = "black",
    cohens_d = sapply(rownames(.), function(comp) {
      groups <- strsplit(comp, "-")[[1]]
      calculate_cohens_d(
        stats_data %>% filter(plate_type == "black", timepoint == "T4"),
        "Section", "OD", groups[1], groups[2]
      )
    })
  ) %>%
  filter(p.adj <= 0.05) %>%
  rownames_to_column(var = "comparison")

# T5
clear_tukey_t5 <- data.frame(TukeyHSD(clear_aov_t5, conf.level = 0.95)$`factor(Section)`) %>%
  mutate(
    timepoint = "T5", 
    plate_type = "clear",
    cohens_d = sapply(rownames(.), function(comp) {
      groups <- strsplit(comp, "-")[[1]]
      calculate_cohens_d(
        stats_data %>% filter(plate_type == "clear", timepoint == "T5"),
        "Section", "OD", groups[1], groups[2]
      )
    })
  ) %>%
  filter(p.adj <= 0.05) %>%
  rownames_to_column(var = "comparison")

black_tukey_t5 <- data.frame(TukeyHSD(black_aov_t5, conf.level = 0.95)$`factor(Section)`) %>%
  mutate(
    timepoint = "T5", 
    plate_type = "black",
    cohens_d = sapply(rownames(.), function(comp) {
      groups <- strsplit(comp, "-")[[1]]
      calculate_cohens_d(
        stats_data %>% filter(plate_type == "black", timepoint == "T5"),
        "Section", "OD", groups[1], groups[2]
      )
    })
  ) %>%
  filter(p.adj <= 0.05) %>%
  rownames_to_column(var = "comparison")

# T6
clear_tukey_t6 <- data.frame(TukeyHSD(clear_aov_t6, conf.level = 0.95)$`factor(Section)`) %>%
  mutate(
    timepoint = "T6", 
    plate_type = "clear",
    cohens_d = sapply(rownames(.), function(comp) {
      groups <- strsplit(comp, "-")[[1]]
      calculate_cohens_d(
        stats_data %>% filter(plate_type == "clear", timepoint == "T6"),
        "Section", "OD", groups[1], groups[2]
      )
    })
  ) %>%
  filter(p.adj <= 0.05) %>%
  rownames_to_column(var = "comparison")

black_tukey_t6 <- data.frame(TukeyHSD(black_aov_t6, conf.level = 0.95)$`factor(Section)`) %>%
  mutate(
    timepoint = "T6", 
    plate_type = "black",
    cohens_d = sapply(rownames(.), function(comp) {
      groups <- strsplit(comp, "-")[[1]]
      calculate_cohens_d(
        stats_data %>% filter(plate_type == "black", timepoint == "T6"),
        "Section", "OD", groups[1], groups[2]
      )
    })
  ) %>%
  filter(p.adj <= 0.05) %>%
  rownames_to_column(var = "comparison")

# Combine all results
tukey_data <- bind_rows(clear_tukey_t2, black_tukey_t2, clear_tukey_t3, black_tukey_t3, 
                       clear_tukey_t4, black_tukey_t4, clear_tukey_t5, black_tukey_t5, 
                       clear_tukey_t6, black_tukey_t6)

# Create final table with effect sizes
tukey_data_table <- tukey_data %>%
  select(plate_type, timepoint, comparison, p.adj, cohens_d) %>%
  rename(`Plate Type` = plate_type,
         Timepoint = timepoint,
         `Section Comparison` = comparison,
         `p-value (adj)` = p.adj,
         `Cohen's d` = cohens_d) %>%
  mutate(`Cohen's d` = round(`Cohen's d`, 3))

# Display results
kable(tukey_data_table)
```

```{r plate_type_plots_stats_photopigment_calcs}
calculate_cohens_d_ttest <- function(t_test_result) {
  t <- t_test_result$statistic
  df <- t_test_result$parameter
  d <- t * sqrt(1/df + 1/(df + 2))
  return(d)
}

calculate_partial_eta_squared <- function(aov_model) {
  anova_table <- summary(aov_model)[[1]]
  ss_effect <- anova_table[1, "Sum Sq"]
  ss_total <- sum(anova_table[, "Sum Sq"])
  partial_eta_squared <- ss_effect / ss_total
  return(partial_eta_squared)
}

# Data preparation
stats_data_pigment <- rel_distribution_data %>%
  filter(timepoint == "T4") %>%
  filter(wavelength != 684)

# T-tests with effect sizes
t.test_444 <- t.test(OD ~ plate_type, data = stats_data_pigment %>% filter(wavelength == 444))
t.test_444
d_444 <- calculate_cohens_d_ttest(t.test_444)
d_444

t.test_495 <- t.test(OD ~ plate_type, data = stats_data_pigment %>% filter(wavelength == 495))
t.test_495
d_495 <- calculate_cohens_d_ttest(t.test_495)
d_495

t.test_634 <- t.test(OD ~ plate_type, data = stats_data_pigment %>% filter(wavelength == 634))
t.test_634
d_634 <- calculate_cohens_d_ttest(t.test_634)
d_634

# T-test results summary
ttest_results <- data.frame(
  Wavelength = c("444", "495", "634"),
  p_value = c(t.test_444$p.value, t.test_495$p.value, t.test_634$p.value),
  cohens_d = c(d_444, d_495, d_634)
) %>%
  mutate(
    Significant = case_when(
      p_value < 0.05 ~ "Yes",
      TRUE ~ "No"
    ),
    # Format p-values to show scientific notation for very small values
    p_value = format(p_value, scientific = TRUE, digits = 3),
    cohens_d = round(cohens_d, 3)
  )

kable(ttest_results)

clear_aov_t5_444 <- aov(OD ~ factor(Section), data = stats_data_pigment %>% filter(plate_type == "clear", wavelength == 444))
black_aov_t5_444 <- aov(OD ~ factor(Section), data = stats_data_pigment %>% filter(plate_type == "black", wavelength == 444))
summary(clear_aov_t5_444)
# summary(black_aov_t5_444)

clear_aov_t5_495 <- aov(OD ~ factor(Section), data = stats_data_pigment %>% filter(plate_type == "clear", wavelength == 495))
black_aov_t5_495 <- aov(OD ~ factor(Section), data = stats_data_pigment %>% filter(plate_type == "black", wavelength == 495))
summary(clear_aov_t5_495)
# summary(black_aov_t5_495)

clear_aov_t5_634 <- aov(OD ~ factor(Section), data = stats_data_pigment %>% filter(plate_type == "clear", wavelength == 634))
black_aov_t5_634 <- aov(OD ~ factor(Section), data = stats_data_pigment %>% filter(plate_type == "black", wavelength == 634))
summary(clear_aov_t5_634)
# summary(black_aov_t5_634)
```

```{r plate_type_plots_stats_photopigment_summary}
anova_results_pigment <- data.frame(
  `Plate Type` = c("clear", 'black', "clear", 'black', "clear", 'black'),
  Wavelength = c("444", "444", "495", "495", "634", "634"),
  p = c(
    summary(clear_aov_t5_444)[[1]][["Pr(>F)"]][1],
    summary(black_aov_t5_444)[[1]][["Pr(>F)"]][1],
    summary(clear_aov_t5_495)[[1]][["Pr(>F)"]][1],
    summary(black_aov_t5_495)[[1]][["Pr(>F)"]][1],
    summary(clear_aov_t5_634)[[1]][["Pr(>F)"]][1],
    summary(black_aov_t5_634)[[1]][["Pr(>F)"]][1]
  ),
  partial_eta_squared = c(
    calculate_partial_eta_squared(clear_aov_t5_444),
    calculate_partial_eta_squared(black_aov_t5_444),
    calculate_partial_eta_squared(clear_aov_t5_495),
    calculate_partial_eta_squared(black_aov_t5_495),
    calculate_partial_eta_squared(clear_aov_t5_634),
    calculate_partial_eta_squared(black_aov_t5_634)
  )
) %>%
  mutate(
    Significant = case_when(
      p < 0.05 ~ "Yes",
      p > 0.05 ~ "No"
    ),
    partial_eta_squared = round(partial_eta_squared, 3)
  )

cohens_f(clear_aov_t5_444)
# cohens_f(black_aov_t5_444)
cohens_f(clear_aov_t5_495)
# cohens_f(black_aov_t5_495)
cohens_f(clear_aov_t5_634)
# cohens_f(black_aov_t5_634)

kable(anova_results_pigment)
```

```{r plate_type_plots_stats_photopigment_summary_tukey}
clear_tukey_444 <- data.frame(TukeyHSD(clear_aov_t5_444, conf.level = 0.95)$`factor(Section)`) %>%
  mutate(
    Wavelength = 444, 
    plate_type = "clear",
    cohens_d = sapply(rownames(.), function(comp) {
      groups <- strsplit(comp, "-")[[1]]
      calculate_cohens_d(
        stats_data_pigment %>% filter(plate_type == "clear", wavelength == 444),
        "Section", "OD", groups[1], groups[2]
      )
    })
  ) %>%
  filter(p.adj <= 0.05) %>%
  rownames_to_column(var = "comparison")

# 444nm Black
black_tukey_444 <- data.frame(TukeyHSD(black_aov_t5_444, conf.level = 0.95)$`factor(Section)`) %>%
  mutate(
    Wavelength = 444, 
    plate_type = "black",
    cohens_d = sapply(rownames(.), function(comp) {
      groups <- strsplit(comp, "-")[[1]]
      calculate_cohens_d(
        stats_data_pigment %>% filter(plate_type == "black", wavelength == 444),
        "Section", "OD", groups[1], groups[2]
      )
    })
  ) %>%
  filter(p.adj <= 0.05) %>%
  rownames_to_column(var = "comparison")

# 495nm Clear
clear_tukey_495 <- data.frame(TukeyHSD(clear_aov_t5_495, conf.level = 0.95)$`factor(Section)`) %>%
  mutate(
    Wavelength = 495, 
    plate_type = "clear",
    cohens_d = sapply(rownames(.), function(comp) {
      groups <- strsplit(comp, "-")[[1]]
      calculate_cohens_d(
        stats_data_pigment %>% filter(plate_type == "clear", wavelength == 495),
        "Section", "OD", groups[1], groups[2]
      )
    })
  ) %>%
  filter(p.adj <= 0.05) %>%
  rownames_to_column(var = "comparison")

# 495nm Black
black_tukey_495 <- data.frame(TukeyHSD(black_aov_t5_495, conf.level = 0.95)$`factor(Section)`) %>%
  mutate(
    Wavelength = 495, 
    plate_type = "black",
    cohens_d = sapply(rownames(.), function(comp) {
      groups <- strsplit(comp, "-")[[1]]
      calculate_cohens_d(
        stats_data_pigment %>% filter(plate_type == "black", wavelength == 495),
        "Section", "OD", groups[1], groups[2]
      )
    })
  ) %>%
  filter(p.adj <= 0.05) %>%
  rownames_to_column(var = "comparison")

# 634nm Clear
clear_tukey_634 <- data.frame(TukeyHSD(clear_aov_t5_634, conf.level = 0.95)$`factor(Section)`) %>%
  mutate(
    Wavelength = 634, 
    plate_type = "clear",
    cohens_d = sapply(rownames(.), function(comp) {
      groups <- strsplit(comp, "-")[[1]]
      calculate_cohens_d(
        stats_data_pigment %>% filter(plate_type == "clear", wavelength == 634),
        "Section", "OD", groups[1], groups[2]
      )
    })
  ) %>%
  filter(p.adj <= 0.05) %>%
  rownames_to_column(var = "comparison")

# 634nm Black
black_tukey_634 <- data.frame(TukeyHSD(black_aov_t5_634, conf.level = 0.95)$`factor(Section)`) %>%
  mutate(
    Wavelength = 634, 
    plate_type = "black",
    cohens_d = sapply(rownames(.), function(comp) {
      groups <- strsplit(comp, "-")[[1]]
      calculate_cohens_d(
        stats_data_pigment %>% filter(plate_type == "black", wavelength == 634),
        "Section", "OD", groups[1], groups[2]
      )
    })
  ) %>%
  filter(p.adj <= 0.05) %>%
  rownames_to_column(var = "comparison")

# Combine all results
tukey_data_pigment <- bind_rows(
  clear_tukey_444, black_tukey_444,
  clear_tukey_495, black_tukey_495,
  clear_tukey_634, black_tukey_634
)

# Create final table with effect sizes
tukey_data_table_pigment <- tukey_data_pigment %>%
  select(plate_type, Wavelength, comparison, p.adj, cohens_d) %>%
  rename(`Plate Type` = plate_type,
         `Section Comparison` = comparison,
         `p-value (adj)` = p.adj,
         `Cohen's d` = cohens_d) %>%
  mutate(`Cohen's d` = round(`Cohen's d`, 3))

# Display results
kable(ttest_results, caption = "T-test Results with Effect Sizes")
kable(anova_results_pigment, caption = "ANOVA Results with Effect Sizes")
kable(tukey_data_table_pigment, caption = "Tukey Test Results with Effect Sizes")
```

\newpage

## Medium Testing

Related figures:

  - Figure 3A
  - Figure 3B

```{r BG11_import}
BG11_picklist <- read_csv('data/use-cases/primary/2973_BG11_plate_layout.csv') %>%
  filter(experiment == 'BG11') %>%
  filter(transfer_compound == compound) %>%
  select(-c(`Source Plate Name`, `Source Well`, transfer_compound, experiment)) %>%
  rename(well = 'Destination Well', destination = 'Destination Plate Name')

plate_metadata <- read_csv('data/use-cases/primary/2973_BG11_plate_metadata.csv')

OD_data_BG11 <- read_csv('data/use-cases/primary/2973_BG11_growth_data.csv') %>%
  mutate(time = ymd_hms(time), timepoint = factor(timepoint, levels = c('T0', 'T1', 'T2', 'T3', 'T4', 'T5', 'T6', 'T7', 'T8', 'T9', 'T10', 'T11', 'T12', 'T13', 'T14', 'T15', 'T16', 'T17', 'T18'))) %>%
  select(-c(sample, datetime)) %>%
  right_join(plate_metadata, by = 'plate_location') %>%
  right_join(layout_info, by = 'well') %>%
  mutate(OD = as.numeric(OD))

BG11_data <- OD_data_BG11 %>%
  filter(experiment == 'BG11') %>%
  inner_join(BG11_picklist, by = c('well', 'destination')) %>%
  mutate(concentration_labs = as.character(concentration),
         concentration_labs = case_when(concentration_labs == '0.033333333' ~ '0.03',
                                        concentration_labs == '0.666666667' ~ '0.67',
                                        concentration_labs == '1.333333333' ~ '1.33',
                                        concentration_labs == '1.666666667' ~ '1.67',
                                        TRUE ~ concentration_labs)) %>%
  mutate(concentration_labs = factor(concentration_labs, levels = c('0', '0.03', '0.1', '0.2', '0.4', '0.67', '1', '1.1', '1.33', '1.67', '2'))) %>%
  mutate(plate_num = case_when(plate_location == 'deckDeck118' ~ 'Layout 1', 
                               plate_location == 'deckDeck117' ~ 'Layout 2', 
                               plate_location == 'deckDeck116' ~ 'Layout 1', 
                               plate_location == 'deckDeck115' ~ 'Layout 2',)) %>%
  separate(well, into = c('row', 'column'), sep = 1, remove = FALSE) %>%
  mutate(column = as.numeric(column))

T0_BG11_data <- BG11_data %>%
  filter(timepoint == 'T0') %>%
  select(well, OD, plate_location) %>%
  rename(T0_OD = 'OD')
```

```{r BG11_plots}
fig3a <- BG11_data %>%
  group_by(compound, concentration, timepoint) %>%
  summarise(OD750 = median(OD)) %>%
  ggplot(aes(x=timepoint, y=OD750, colour = concentration, group = concentration)) +
  geom_line() + 
  facet_wrap(~compound, scales = 'free_y', ncol = 2) +
  labs(color = 'Concentration \n (x-fold BG11)', x= 'Timepoint', y = bquote(OD[750])) +
  scale_colour_gradient(low = "black", high = "springgreen3", na.value = NA) +
  theme(legend.position="bottom",
        legend.title = element_text(vjust=1))

fig3b <- BG11_data %>%
  filter(timepoint == 'T3') %>%
  filter(OD < 0.8) %>%
  ggplot(aes(x=concentration_labs, y=OD, group = concentration_labs, color = Section)) +
  geom_boxplot(outlier.shape = NA, show.legend = FALSE) + 
  geom_jitter() +
  facet_wrap(~compound, scales = 'free_y', ncol = 2) +
  labs(x = 'Concentration (x-fold BG11)', y = bquote(OD[750])) +
  theme(axis.text.x = element_text(angle = 90)) +
  theme(legend.position="bottom",
        legend.title = element_text(vjust=0.75))

fig3ab <- plot_grid(fig3a, fig3b,
          ncol = 2,
          labels = c('A', 'B'),
          label_size = 14,
          rel_widths = c(3, 3))
fig3ab
```

## Antibiotics Testing

Related figures:

  - Figure 3C
  - Figure 3D

```{r antibiotics_import}
well_layout <- read_csv('data/use-cases/primary/antiobiotics_plate_layout.csv')
plate_metadata <- read_csv('data/use-cases/primary/antiobiotics_plate_metadata.csv')
layout_info <- read_csv('data/use-cases/primary/layout_info.csv')

OD_data_antibiotics <- read_csv('data/use-cases/primary/antibiotics_growth_data.csv') %>%
  mutate(time = ymd_hms(time), timepoint = factor(timepoint, levels = c('T0', 'T1', 'T2', 'T3', 'T4', 'T5', 'T6', 'T7', 'T8', 'T9', 'T10', 'T11', 'T12', 'T13', 'T14', 'T15', 'T16', 'T17', 'T18'))) %>%
  select(-c(sample, datetime)) %>%
  right_join(well_layout, by = 'well') %>%
  right_join(plate_metadata, by = 'ID1') %>%
  inner_join(layout_info, by = 'well') %>%
  mutate(Concentration = Concentration * 50, concentration_labs = factor(as.character(Concentration), levels = c('0', '0.5', '2.5', '5', '10', '25', '50', '75', '100', '250', '500'))) %>%
  mutate(Antibiotic = case_when(Antibiotic == "Carbanicillin" ~ "Carbenicillin",
                                TRUE ~ Antibiotic))
```

```{r antibiotics_plots}
fig3c <- OD_data_antibiotics %>%
  group_by(Antibiotic, Strain, Concentration, timepoint) %>%
  filter(Strain == "UTEX2973") %>%
  summarise(OD750 = median(OD750)) %>%
  ggplot(aes(x=timepoint, y=OD750, colour = Concentration, group = Concentration)) +
  geom_line() + 
  facet_wrap(~Antibiotic, scales = 'free_y', ncol = 1) +
  scale_colour_gradient(low = "black", high = "springgreen3", na.value = NA) +
  labs(y = bquote(OD[750]), x="Timepoint", color = 'Concentration\n(mg/L)') +
  theme(legend.position="bottom",
        legend.title = element_text(vjust=1))
fig3c

fig3d <- OD_data_antibiotics %>%
  filter(timepoint == 'T5') %>%
  filter(Strain == "UTEX2973") %>%
  ggplot(aes(x=concentration_labs, y=OD750, group = concentration_labs, colour = Section)) +
  geom_boxplot(outlier.shape = NA) + 
  geom_jitter() +
  facet_wrap(~Antibiotic, scales = 'free_y', ncol = 1) +
  labs(x = 'Concentration (mg/ml)', y = bquote(OD[750])) +
  theme(axis.text.x = element_text(angle = 90)) +
  theme(legend.position="bottom",
        legend.title = element_text(vjust=0.75))
fig3d

fig3cd <- plot_grid(fig3c, fig3d,
          ncol = 2,
          labels = c('C', 'D'),
          label_size = 14,
          rel_widths = c(3, 3))
fig3cd
```

```{r nature_fig_3}
nat_fig3 <- plot_grid(fig3ab, fig3cd,
          ncol = 2,
          labels = c('', ''),
          label_size = 14,
          rel_widths = c(5, 3))
nat_fig3
```

## BG11 Medium Optimization

Related figures:

  - Figure 4B
  - Figure 4C
  - Supplementary Figure 27

```{r BG11_opt_import}
JMP_picklist <- read_csv("data/use-cases/BG11-RSM/BG11_JMP_layout.csv") %>%
  filter(`Destination Plate Name` == 'Destination[1]') %>%
  rename(transfer_vol = `Transfer Volume`, well = `Destination Well`) %>%
  mutate(transfer_vol = case_when(transfer_vol == 1500 ~ 150,
                                  transfer_vol == 750 ~ 75,
                                  TRUE ~ transfer_vol)) %>%
  mutate(JMP_value = case_when(transfer_vol == 0 ~ -1,
                               transfer_vol == 75 ~ 0,
                               transfer_vol == 150 ~ 1)) %>%
  select(JMP_value, well, compound) %>%
  pivot_wider(names_from = "compound", values_from = "JMP_value")

OD_data_output <- read_csv("data/use-cases-mod/BG11-RSM/BG11_opt_OD_data.csv", col_types = cols(plate_ID = col_character())) %>%
  select(-c(datetime, measurement_ID)) %>%
  mutate(time = ymd_hms(time), timepoint = factor(timepoint, levels = c('T0', 'T1', 'T2', 'T3', 'T4', 'T5', 'T6', 'T7', 'T8', 'T9', 'T10', 'T11', 'T12', 'T13', 'T14', 'T15', 'T16', 'T17', 'T18'))) %>%
  filter(wavelength == 750) %>%
  select(-c(time, wavelength)) %>%
  mutate(OD = as.numeric(OD)) %>%
  pivot_wider(names_from = timepoint, values_from = OD) %>%
  mutate(OD = T3-T0) %>%
  select(plate_ID, well, OD) %>%
  right_join(JMP_picklist, by = "well") %>%
  select(plate_ID, NaNO3, K2HPO4, MgSO4, CaCl2, EDTA, Na2CO3, Citrate, `Trace elements`, OD)

effect_summary_import <- read_csv("data/use-cases/BG11-RSM/effect_summary_table.csv") %>%
  mutate(c_added = case_when(strain == "UTEX2973" ~ "- Ci",
                             strain == "UTEX2973_C" ~ "+ Ci",
                             strain == "nostoc" ~ "- Ci",
                             strain == "nostoc_C" ~ "+ Ci",
                             strain == "UTEX90" ~ "- Ci",
                             strain == "UTEX90_C" ~ "+ Ci"),
         strain_name = case_when(strain == "UTEX2973" ~ "UTEX2973",
                            strain == "UTEX2973_C" ~ "UTEX2973",
                            strain == "nostoc" ~ "Nostoc hatei",
                            strain == "nostoc_C" ~ "Nostoc hatei",
                            strain == "UTEX90" ~ "UTEX90",
                            strain == "UTEX90_C" ~ "UTEX90"),
         strain_order = case_when(strain_name == "UTEX2973" ~ 1,
                            strain_name == "UTEX90" ~ 2,
                            strain_name == "Nostoc hatei" ~ 3),
         c_order = case_when(c_added == "+ Ci" ~ 1,
                             c_added == "- Ci" ~ 2)) %>%
  group_by(Source) %>%
  mutate(order = median(Logworth))
```

```{r bg11_opt_plots}
fig4b <- effect_summary_import %>%
  filter(str_detect(Source, "\\*", negate = T)) %>%
  ggplot(aes(x = Logworth, y = reorder(Source, order))) +
  geom_col(fill = "palegreen4") +
  facet_grid(cols = vars(reorder(strain_name, strain_order)), rows = vars(reorder(c_added, c_order))) +
  labs(x = "LogWorth [-log10(p-value)]", y = NULL)
fig4b

NaNO3_data <- OD_data_output %>%
  mutate(strain = case_when(plate_ID == "2973" ~ "UTEX2973 (- Ci)",
                            plate_ID == "2973_C" ~ "UTEX2973 (+ Ci)",
                            plate_ID == "nostoc" ~ "Nostoc hatei (- Ci)",
                            plate_ID == "nostoc_C" ~ "Nostoc hatei (+ Ci)",
                            plate_ID == "UTEX90" ~ "UTEX90 (- Ci)",
                            plate_ID == "UTEX90_C" ~ "UTEX90 (+ Ci)"),
         c_added = case_when(plate_ID == "2973" ~ F,
                            plate_ID == "2973_C" ~ T,
                            plate_ID == "nostoc" ~ F,
                            plate_ID == "nostoc_C" ~ T,
                            plate_ID == "UTEX90" ~ F,
                            plate_ID == "UTEX90_C" ~ T),
         strain_order = case_when(str_detect(plate_ID, "2973") ~ 1,
                                  str_detect(plate_ID, "UTEX90") ~ 2,
                                  str_detect(plate_ID, "Nostoc") ~ 3)) %>%
  # filter(c_added == T) %>%
  # mutate(condition_string = paste(NaNO3, K2HPO4, MgSO4, CaCl2, EDTA, Na2CO3, Citrate, `Trace elements`, sep = "/")) %>%
  mutate(Depleted = case_when((NaNO3 == -1) ~ "No",
                              TRUE ~ "Yes"),
         Depleted_order = case_when(Depleted == "Yes" ~ 1,
                                    Depleted == "No" ~ 2)) %>%
  mutate(inc_compound = "NaNO3",
         facet_order = 1)

K2HPO4_data <- OD_data_output %>%
  mutate(strain = case_when(plate_ID == "2973" ~ "UTEX2973 (- Ci)",
                            plate_ID == "2973_C" ~ "UTEX2973 (+ Ci)",
                            plate_ID == "nostoc" ~ "Nostoc hatei (- Ci)",
                            plate_ID == "nostoc_C" ~ "Nostoc hatei (+ Ci)",
                            plate_ID == "UTEX90" ~ "UTEX90 (- Ci)",
                            plate_ID == "UTEX90_C" ~ "UTEX90 (+ Ci)"),
         c_added = case_when(plate_ID == "2973" ~ F,
                            plate_ID == "2973_C" ~ T,
                            plate_ID == "nostoc" ~ F,
                            plate_ID == "nostoc_C" ~ T,
                            plate_ID == "UTEX90" ~ F,
                            plate_ID == "UTEX90_C" ~ T),
         strain_order = case_when(str_detect(plate_ID, "2973") ~ 1,
                                  str_detect(plate_ID, "UTEX90") ~ 2,
                                  str_detect(plate_ID, "Nostoc") ~ 3)) %>%
  # filter(c_added == T) %>%
  mutate(Depleted = case_when((K2HPO4 == -1) ~ "No",
                              TRUE ~ "Yes"),
         Depleted_order = case_when(Depleted == "Yes" ~ 1,
                                    Depleted == "No" ~ 2)) %>%
  mutate(inc_compound = "K2HPO4",
         facet_order = 3)

MgSO4_data <- OD_data_output %>%
  mutate(strain = case_when(plate_ID == "2973" ~ "UTEX2973 (- Ci)",
                            plate_ID == "2973_C" ~ "UTEX2973 (+ Ci)",
                            plate_ID == "nostoc" ~ "Nostoc hatei (- Ci)",
                            plate_ID == "nostoc_C" ~ "Nostoc hatei (+ Ci)",
                            plate_ID == "UTEX90" ~ "UTEX90 (- Ci)",
                            plate_ID == "UTEX90_C" ~ "UTEX90 (+ Ci)"),
         c_added = case_when(plate_ID == "2973" ~ F,
                            plate_ID == "2973_C" ~ T,
                            plate_ID == "nostoc" ~ F,
                            plate_ID == "nostoc_C" ~ T,
                            plate_ID == "UTEX90" ~ F,
                            plate_ID == "UTEX90_C" ~ T),
         strain_order = case_when(str_detect(plate_ID, "2973") ~ 1,
                                  str_detect(plate_ID, "UTEX90") ~ 2,
                                  str_detect(plate_ID, "Nostoc") ~ 3)) %>%
  # filter(c_added == T) %>%
  mutate(Depleted = case_when((MgSO4 == -1) ~ "No",
                              TRUE ~ "Yes"),
         Depleted_order = case_when(Depleted == "Yes" ~ 1,
                                    Depleted == "No" ~ 2)) %>%
  mutate(inc_compound = "MgSO4",
         facet_order = 2)

central_data <- OD_data_output %>%
  mutate(condition_string = paste(NaNO3, K2HPO4, MgSO4, CaCl2, EDTA, Na2CO3, Citrate, `Trace elements`, sep = "/")) %>%
  filter(condition_string == "0/0/0/0/0/0/0/0") %>%
  group_by(plate_ID) %>%
  summarise(median_central = median(OD))

depleted_data <- bind_rows(NaNO3_data, K2HPO4_data, MgSO4_data) %>%
  left_join(central_data, by = "plate_ID")

depletion_fig <- depleted_data %>%
  ggplot(aes(y = OD, x = plate_ID, color = reorder(Depleted, Depleted_order))) +
  geom_jitter() +
  geom_hline(aes(yintercept = median_central), linetype = "dashed") +
  labs(y = bquote(OD[750]), colour = "Compound\nin media") +
  facet_grid(cols = vars(reorder(strain, strain_order)), rows = vars(reorder(inc_compound, facet_order)), scales = "free_x") +
  theme(axis.text.x = element_blank(),
        axis.ticks.x = element_blank(),
        axis.title.x = element_blank())
depletion_fig
```

### BG-11 Optimization - Flask-scale validation

```{r flask_validation}
flask_biomass_import <- read_csv("data/use-cases/BG11-RSM/flask_biomass_data_v2.csv") %>%
  mutate(delta_biomass_mg = (biomass*1000)-(T0*1000)) %>%
  mutate(biomass_mgl = delta_biomass_mg*1000/volume)

flask_biomass_import_bg11 <- flask_biomass_import %>%
  filter(experiment == "optimization")

flask_biomass_summary_bg11 <- flask_biomass_import_bg11 %>%
  group_by(condition, carbon, strain, strain_order) %>%
  summarize(biomass_mean = mean(biomass_mgl))

flask_fold_increase_table_bg11 <- flask_biomass_summary_bg11 %>%
  select(condition, strain, carbon, biomass_mean) %>%
  pivot_wider(names_from = condition, values_from = biomass_mean) %>%
  mutate(fold_change = Optimized/Standard*100) %>%
  mutate(condition = "Standard")
flask_fold_increase_table_bg11

fig4c <- ggplot() +
  geom_col(data = flask_biomass_summary_bg11, aes(y = biomass_mean, x = reorder(condition, desc(condition)), fill = reorder(condition, desc(condition))), width = 0.7) +
  geom_jitter(data = flask_biomass_import_bg11, aes(y = biomass_mgl, x = condition)) +
  geom_hline(data = flask_fold_increase_table_bg11, aes(yintercept = Optimized), linetype = "dashed") +
  geom_text(data = flask_fold_increase_table_bg11, aes(x = condition, y = Optimized,label = paste0(round(fold_change, 1),"%")), vjust = -0.5, hjust = 0.6, size = 3.5) +
  facet_nested(~ reorder(carbon, desc(carbon)) + strain) +
  labs(y = "Dry weight (mg/L)", x = NULL, fill = "BG-11 Medium") +
  scale_fill_manual(values = c("palegreen2", "palegreen4")) +
  theme(strip.background = element_rect(colour = "white"),
        axis.text.x = element_blank(),
        legend.position = "bottom")
fig4c
```

```{r nature_fig_4}
nat_fig4 <- plot_grid(fig4b, fig4c,
          ncol = 2,
          labels = c('B', 'C'),
          label_size = 14,
          rel_widths = c(3,3))
nat_fig4
```

## Bioactive molecule screen

  - Figure 5
  - Supplementary Figure 28
  - Supplementary Figure 29

```{r screening_data_import}
# Screen 1
layout_info <- read_csv('data/use-cases/bioactive-screening/layout_info.csv')

library_data <- read_csv("data/use-cases/bioactive-screening/bioactive_library_info.csv", locale = readr::locale(encoding = "latin1")) %>%
  rowwise() %>%
  mutate(split_plate_ID = str_split(`384-Barcode`, pattern = '-'),
         plate_ID = rev(split_plate_ID)[1]) %>%
  select(-c(split_plate_ID, `ID number`, `Source Plate&Well`)) %>%
  rename(well = "384-Well") %>%
  mutate(plate_ID = as.numeric(plate_ID))

screen1_OD_data <- read_csv('data/use-cases-mod/bioactive-screening/bioactive_screen1_OD_data.csv') %>%
  mutate(time = ymd_hms(time), timepoint = factor(timepoint, levels = c('T0', 'T1', 'T2', 'T3', 'T4', 'T5', 'T6', 'T7', 'T8', 'T9', 'T10', 'T11', 'T12', 'T13', 'T14', 'T15', 'T16', 'T17', 'T18'))) %>%
  select(-c(datetime)) %>%
  mutate(value_ID = interaction(measurement_ID, well)) %>%
  mutate(round = case_when(plate_ID %in% c(1209, 1212, 1215, 1221, 1224, 1227, 1230, 1243, 1247) ~ "Set 1",
                  plate_ID %in% c(1236, 1239, 1251, 1255, 1258) ~ "Set 2")) %>%
  mutate(Day = case_when(timepoint == "T0" ~ "0",
                         timepoint == "T1" ~ "3",
                         timepoint == "T2" ~ "5"))

screening_data <- screen1_OD_data %>%
  inner_join(library_data, by = c("well", "plate_ID"))

compound_list <- screening_data %>%
  select(plate_ID, well, `Chemical name`, Formula, `384-Barcode&Well`) %>%
  distinct()
```

\newpage

### Bioactive screen - Round 1

#### OD~750~ Hit Identification

 - The following plots show hit selection for increased growth rate, based on OD~750~
 - Hits were selected based on $Z$-score, where $Z \ge \pm 2.5$

```{r screen1_OD750}
hit_tally <- screen1_OD_data %>%
  filter(str_detect(well, '01', negate = TRUE), str_detect(well, '24', negate = TRUE)) %>%
  filter(wavelength == 750, timepoint == "T2") %>%
  ungroup() %>%
  group_by(plate_ID) %>%
  mutate(z_score = (OD-mean(OD))/sd(OD)) %>%
  mutate(hit = case_when(z_score >= 2.5 ~ "yes", 
                         z_score <= -2.5 ~ "yes",
                         TRUE ~ "no"),
         hit_side = case_when(z_score >= 2.5 ~ "high", 
                         z_score <= -2.5 ~ "low",
                         TRUE ~ "no")) %>%
  left_join(compound_list, by = c("plate_ID", "well")) %>%
  filter(!is.na(`Chemical name`)) %>%
  group_by(hit, hit_side) %>%
  tally() %>%
  rename(Hit = hit, `Hit Type` = 'hit_side', Count = "n")

# write_csv(hit_tally, "bioactive_round1_tally.csv")

kbl(hit_tally)

hit_overview <- screen1_OD_data %>%
  filter(str_detect(well, '01', negate = TRUE), str_detect(well, '24', negate = TRUE)) %>%
  filter(wavelength == 750, timepoint == "T2") %>%
  ungroup() %>%
  group_by(plate_ID) %>%
  mutate(z_score = (OD-mean(OD))/sd(OD)) %>%
  mutate(hit = case_when(z_score >= 2.5 ~ "yes", 
                         z_score <= -2.5 ~ "yes",
                         TRUE ~ "no"),
         hit_side = case_when(z_score >= 2.5 ~ "high", 
                         z_score <= -2.5 ~ "low",
                         TRUE ~ "no")) %>%
  filter(hit == "yes") %>%
  left_join(compound_list, by = c("plate_ID", "well")) %>%
  select(plate_ID, well, hit_side, z_score, `Chemical name`, Formula) %>%
  filter(!is.na(`Chemical name`))

# write_csv(hit_overview, "bioactive_round1_hits.csv")

kbl(hit_overview)

mycolors = colorRampPalette(brewer.pal(name="Dark2", n = 8))(14)
primary_figA <- screen1_OD_data %>%
  filter(str_detect(well, '01', negate = TRUE), str_detect(well, '24', negate = TRUE)) %>%
  filter(wavelength == 750, timepoint == "T2") %>%
  group_by(round) %>%
  mutate(median = median(OD)) %>%
  ggplot() +
  geom_point(aes(y = OD, x = fct_reorder(value_ID, plate_ID), color = as.character(plate_ID)), show.legend = FALSE) +
  geom_line(aes(y = median, x = fct_reorder(value_ID, plate_ID), group = round), size = 0.5, linetype = "solid") +
  labs(x = NULL, y = bquote(OD[750]), color = "Plate") + #, title = "OD750 values accross plates"
  theme(axis.text.x=element_blank(), 
        axis.ticks.x=element_blank()) +
  facet_grid(cols = vars(round), scales = "free", space = "free") +
  scale_colour_manual(values = c("grey80", "grey65","grey80", "grey65","grey80", "grey65","grey80", "grey65","grey80", "grey65","grey80", "grey65","grey80", "grey65"))
primary_figA

z_score_data <- screen1_OD_data %>%
  filter(str_detect(well, '01', negate = TRUE), str_detect(well, '24', negate = TRUE)) %>%
  filter(wavelength == 750, timepoint == "T2") %>%
  ungroup() %>%
  group_by(plate_ID) %>%
  mutate(z_score = (OD-mean(OD))/sd(OD))

round1_supp_distribution <- screen1_OD_data %>%
  filter(str_detect(well, '01', negate = TRUE), str_detect(well, '24', negate = TRUE)) %>%
  filter(wavelength == 750, timepoint == "T2") %>%
  ungroup() %>%
  group_by(plate_ID) %>%
  mutate(z_score = (OD-mean(OD))/sd(OD)) %>%
  ggplot() +
  geom_histogram(aes(x = z_score, y = ..density..)) +
  stat_function(fun = dnorm, args = list(mean = mean(z_score_data$z_score), sd = sd(z_score_data$z_score))) +
  labs(x = "Z-score", y = 'Well Proportion')
round1_supp_distribution

primary_figB <- screen1_OD_data %>%
  filter(str_detect(well, '01', negate = TRUE), str_detect(well, '24', negate = TRUE)) %>%
  filter(wavelength == 750, timepoint == "T2") %>%
  ungroup() %>%
  group_by(plate_ID) %>%
  mutate(z_score = (OD-mean(OD))/sd(OD)) %>%
  mutate(hit = case_when(z_score >= 2.5 ~ "Yes", 
                         z_score <= -2.5 ~ "Yes",
                         TRUE ~ "No")) %>%
  ggplot() +
  geom_point(aes(y = z_score, x = fct_reorder(value_ID, plate_ID), color = hit)) +
  geom_hline(aes(yintercept = 0), size = 0.5) +
  geom_hline(aes(yintercept = -2.5), size = 0.5, linetype = "dashed") +
  geom_hline(aes(yintercept = 2.5), size = 0.5, linetype = "dashed") +
  labs(x = NULL, y = 'Z-Score', color = "Hit") + # , title = TeX(r'(Hit selection ($Z\geq \pm 2.5$))')
  theme(axis.text.x=element_blank(), 
        axis.ticks.x=element_blank(),
        legend.position="none"
        ) +
  facet_grid(cols = vars(round), scales = "free", space = "free") +
  scale_colour_manual(values = c("seagreen2", "seagreen"))

primary_figB

skewness_OD <- z_score_data %>%
  group_by(plate_ID) %>%
  summarise(Skew = skewness(z_score), Kurtosis = kurtosis(z_score))
skewness_OD

skewness_OD_full <- z_score_data %>%
  ungroup() %>%
  summarise(Skew = skewness(z_score), Kurtosis = kurtosis(z_score))
skewness_OD_full

primary_figC <- screen1_OD_data %>%
  filter(str_detect(well, '01', negate = TRUE), str_detect(well, '24', negate = TRUE)) %>%
  filter(wavelength == 750, timepoint == "T2") %>%
  ungroup() %>%
  group_by(plate_ID) %>%
  mutate(z_score = (OD-mean(OD))/sd(OD)) %>%
  mutate(placer = "  ") %>%
  ggplot() +
  geom_histogram(aes(x = z_score, y = ..density..)) +
  facet_grid(cols = vars(placer)) +
  labs(x = NULL, y = NULL) + #, title = "Z-score distributions"
  coord_flip() +
  theme(panel.background = element_blank(),
        strip.background=element_rect(fill="white"),
        axis.text.x=element_blank(), 
        axis.ticks.x=element_blank()
        )

primary_figC

select_hits_OD750 <- screen1_OD_data %>%
  filter(str_detect(well, '01', negate = TRUE), str_detect(well, '24', negate = TRUE)) %>%
  filter(wavelength == 750, timepoint == "T2") %>%
  ungroup() %>%
  group_by(plate_ID) %>%
  mutate(z_score = (OD-mean(OD))/sd(OD)) %>%
  mutate(hit = case_when(z_score >= 2.5 ~ "yes", 
                         z_score <= -2.5 ~ "yes",
                         TRUE ~ "no"),
         hit_side = case_when(z_score >= 2.5 ~ "upper", 
                         z_score <= -2.5 ~ "lower",
                         TRUE ~ "no")) %>%
  filter(hit == "yes") %>%
  mutate(selection = "OD750", plate_ID = as.character(plate_ID)) %>%
  select(plate_ID, z_score, well, hit, hit_side, selection)

supp_fig_screen1 <- screen1_OD_data %>%
  filter(str_detect(well, '01', negate = TRUE), str_detect(well, '24', negate = TRUE)) %>%
  filter(wavelength == 750, timepoint == "T2") %>%
  mutate(row = str_sub(well, start = 1L, end = 1L),
         column = as.numeric(str_sub(well, start = 2L, end = 3L))) %>%
  ggplot(aes(x=column, y = reorder(row, desc(row)), fill = OD)) +
  geom_tile() +
  labs(y = '', x = '', fill = bquote(OD[750]), title = "OD750 by well") +
  facet_wrap(vars(plate_ID), scales = "free") +
  theme(axis.text.x = element_text(size = 11),
        axis.text.y = element_text(size = 8),
        axis.title = element_text(size=14), 
        strip.text = element_text(size=14))
supp_fig_screen1

od_panels <- plot_grid(primary_figA, primary_figB, primary_figC,
                  ncol = 3,
                  labels = c("A", "B", "C"),
                  label_size = 14,
                  rel_widths = c(4, 4, 2))
od_panels
```

\newpage

### Bioactive screen - Round 2

#### OD~750~ Hit Identification

The following plots show hit selection for increased growth rate, based on OD~750~.

```{r screen2_OD_data_import}
hit_function_info <- read_csv("data/use-cases/bioactive-screening/bioactive_screen_round2_hit_compound_info.csv", locale = readr::locale(encoding = "latin1"))

round2_OD_data <- read_csv("data/use-cases/bioactive-screening/bioactive_round2_OD_data.csv", locale = readr::locale(encoding = "latin1"))

round2_control_data <- round2_OD_data %>%
  filter(well_type == "Control")

round2_control_data_summary <- round2_control_data %>%
  group_by(plate_ID) %>%
  summarise(control_mean = mean(OD), control_sd = sd(OD))

round2_control_data_sum <- (round2_control_data_summary %>%
  summarise(control_mean = mean(control_mean)))$control_mean

round2_OD_hits <- round2_OD_data %>%
  left_join(round2_control_data_summary, by = "plate_ID") %>%
  ungroup() %>%
  group_by(well) %>%
  mutate(hit_type = case_when(median(OD) > median(control_mean) ~ "higher",
                              median(OD) < median(control_mean) ~ "lower")) %>%
  ungroup() %>%
  
  rowwise() %>%
  mutate(p.value = case_when(hit_type == "lower" ~ pnorm(q = OD, mean = control_mean, sd = control_sd),
                            hit_type == "higher" ~ pnorm(q = OD, mean = control_mean, sd = control_sd, lower.tail = FALSE))) %>%
  rowwise() %>%
  mutate(hit = case_when(p.value <= 0.1 ~ "yes",
                         p.value > 0.1 ~ "no")) %>%
  filter(well_type == "Experimental", hit == "yes") %>%
  group_by(`Chemical name`) %>%
  mutate(n = n()) %>%
  filter(n > 1) %>%
  group_by(timepoint, wavelength, well, `Chemical name`, n, hit_type) %>%
  summarise(med_OD = median(OD), med_p.value= median(p.value)) %>%
  left_join(hit_function_info, by = 'Chemical name')

round2_OD_p_values <- round2_OD_data %>%
  left_join(round2_control_data_summary, by = "plate_ID") %>%
  ungroup() %>%
  group_by(well) %>%
  mutate(hit_type = case_when(median(OD) > median(control_mean) ~ "higher",
                              median(OD) < median(control_mean) ~ "lower")) %>%
  ungroup() %>%
  
  rowwise() %>%
  mutate(p.value = case_when(hit_type == "lower" ~ pnorm(q = OD, mean = control_mean, sd = control_sd),
                            hit_type == "higher" ~ pnorm(q = OD, mean = control_mean, sd = control_sd, lower.tail = FALSE))) %>%
  filter(`Chemical name` %in% round2_OD_hits$`Chemical name`) %>%
  mutate(Reading = case_when(plate_ID == 'rescreen1' ~ 'Rep 1 (p-value)',
                             plate_ID == 'rescreen2' ~ 'Rep 2 (p-value)',
                             plate_ID == 'rescreen3' ~ 'Rep 3 (p-value)')) %>%
  select(c(`Chemical name`, Reading, `p.value`)) %>%
  mutate(p.value = case_when(p.value <= 0.00095 ~ formatC(p.value, format = "e", digits = 2),
                             T ~ as.character(round(p.value, 3)))) %>%
  # mutate(p.value = formatC(p.value, format = "e", digits = 2)) %>%
  pivot_wider(names_from = 'Reading', values_from = 'p.value')

round2_OD_hit_info <- round2_OD_hits %>%
  ungroup() %>%
  select(well, `Chemical name`, n, hit_type)

round2_OD_hits_data <- round2_OD_data %>%
  mutate(hit = case_when(well %in% round2_OD_hits$well ~ "hit")) %>%
  filter(hit == "hit") %>%
  left_join(round2_control_data_summary, by = "plate_ID") %>%
  ungroup() %>%
  select(plate_ID, well, OD, control_mean) %>%
  left_join(round2_OD_hit_info, by = "well") %>%
  mutate(Reading = case_when(plate_ID == 'rescreen1' ~ 'Rep 1 (x-fold)',
                             plate_ID == 'rescreen2' ~ 'Rep 2 (x-fold)',
                             plate_ID == 'rescreen3' ~ 'Rep 3 (x-fold)')) %>%
  select(-plate_ID) %>%
  mutate(fold_OD = OD/control_mean) %>%
  select(-c(OD, control_mean)) %>%
  mutate(fold_OD = round(fold_OD, 3)) %>%
  pivot_wider(names_from = "Reading", values_from = "fold_OD") %>%
  rename(`Significant Measurements` = "n") %>%
  arrange(desc(`Rep 1 (x-fold)`))

round2_OD_hits_select <- round2_OD_hits_data %>%
  ungroup() %>%
  rowwise() %>%
  mutate(dif = round2_control_data_sum - mean(c(`Rep 1 (x-fold)`, `Rep 2 (x-fold)`, `Rep 3 (x-fold)`))) %>%
  mutate(rank = abs(dif)) %>%
  group_by(hit_type) %>%
  slice_max(order_by = rank, n = 8) %>%
  select(-c(dif, rank)) %>%
  inner_join(round2_OD_p_values, by = 'Chemical name') %>%
  select(`Chemical name`, `Significant Measurements`, hit_type, `Rep 1 (x-fold)`, `Rep 1 (p-value)`, `Rep 2 (x-fold)`, `Rep 2 (p-value)`, `Rep 3 (x-fold)`, `Rep 3 (p-value)`)
write_csv(round2_OD_hits_select, 'round2_hits_coverview.csv')
round2_OD_hits_select
```

```{r screen2_OD750}
round2_hit_overview_OD <- round2_OD_data %>%
  mutate(hit = case_when(well %in% round2_OD_hits_select$well ~ "hit", well_type == "Control" ~ "Control")) %>%
  filter(hit == "hit" | hit == "Control")

round2_hits_info <- round2_OD_hits_select %>%
    select(`Chemical name`, `Significant Measurements`, hit_type) %>%
    rename(`Hit Type` = hit_type)

kbl(round2_hits_info, caption = "OD750 Select Hits - Up to 8 hits were selected for each screening condition")

min <- (round2_OD_data %>%
  ungroup() %>%
  summarise(quantile = quantile(OD, 0.01)))$quantile
min

max <- (round2_OD_data %>%
  summarise(quantile = quantile(OD, 0.99)))$quantile
max

round2_figA <- round2_OD_data %>%
  ggplot() +
  geom_point(aes(y = OD, x = fct_reorder(value_ID, plate_ID), color = well_type), show.legend = FALSE) +
  labs(x = NULL, y = bquote(OD[750]), color = "Well Type") +
  theme(axis.text.x=element_blank(), axis.ticks.x=element_blank()) +
  scale_colour_manual(values = c("grey", "seagreen"))
round2_figA

round2_legend <- cowplot::get_legend(round2_OD_data %>%
  ggplot() +
  geom_point(aes(y = OD, x = fct_reorder(value_ID, plate_ID), color = well_type)) +
  labs(x = NULL, y = bquote(OD[750]), color = "Well Type") +
  theme(axis.text.x=element_blank(), axis.ticks.x=element_blank()) +
  scale_colour_manual(values = c("grey", "seagreen")))

round2_figB <- round2_OD_data %>%
  mutate(hit = case_when(well %in% round2_OD_hits_select$well ~ "hit", well_type == "Control" ~ "Control")) %>%
  filter(hit == "hit" | hit == "Control") %>%
  ggplot() +
  geom_point(aes(y = OD, x = fct_reorder(value_ID, plate_ID), color = well_type), show.legend = FALSE) +
  labs(x = NULL, y = bquote(OD[750]), color = "Well Type") +
  theme(axis.text.x=element_blank(), 
        axis.ticks.x=element_blank(),
        legend.key=element_blank()) +
  scale_colour_manual(values = c("grey", "seagreen"))
round2_figB

round2_figC <- round2_OD_data %>%
  filter(well_type == "Control") %>%
  ggplot() +
  geom_histogram(aes(x = OD, y = ..density..)) +
  labs(x = NULL, y = NULL) +
  coord_flip() +
  xlim(0, NA) +
  theme(panel.background = element_blank(),
        strip.background=element_rect(fill="white"),
        axis.text.x=element_blank(), 
        axis.ticks.x=element_blank()
        )
round2_figC

round2_supp_distribution <- round2_control_data %>%
  ggplot() +
  geom_histogram(aes(x = OD, y = ..density..)) +
  stat_function(fun = dnorm, args = list(mean = mean(round2_control_data$OD), sd = sd(round2_control_data$OD))) +
  labs(x = bquote(OD[750]), y = 'Well Proportion')
round2_supp_distribution

skewness_OD <- round2_control_data %>%
  group_by(plate_ID) %>%
  summarise(Skew = skewness(OD), Kurtosis = kurtosis(OD))
skewness_OD

skewness_OD_full <- round2_control_data %>%
  ungroup() %>%
  summarise(Skew = skewness(OD), Kurtosis = kurtosis(OD))
skewness_OD_full

round2_od_panels <- plot_grid(round2_figA, round2_figB, round2_figC,
                  ncol = 3,
                  labels = c("D", "E", "F"),
                  label_size = 14,
                  rel_widths = c(4, 4, 2))
round2_od_panels
```

\newpage

### Bioactive screen - Round 3

#### OD~750~ Hit Testing

 - The following plots show hit testing for increased growth rate, based on OD~750~.

```{r round3_OD_data_import}
round3_OD750_compounds <- round2_OD_hits_select$`Chemical name`

round3_OD750_compounds_df <- round2_OD_hits_select %>%
  rename(Compound = "Chemical name", source_well = "well") %>%
  select(Compound, hit_type, source_well)

round3_layout <- read_csv("data/use-cases/bioactive-screening/bioactive_screen_round3_layout.csv") %>%
  rename(well = "Destination Well", Compound = "Chemical name") %>%
  mutate(Concentration = `Transfer Volume`/75*5) %>%
  select(well, Compound, Concentration) %>%
  mutate(plate_type = "gradient", Concentration = as.character(Concentration))

round3_OD_data <- read_csv("data/use-cases-mod/bioactive-screening/bioactive_screen_round3_OD_data.csv") %>%
  filter(str_detect(well, '01', negate = TRUE), str_detect(well, '24', negate = TRUE), str_detect(well, 'A', negate = TRUE), str_detect(well, 'P', negate = TRUE)) %>%
  filter(wavelength == 750)

round3_OD_control_data <- round3_OD_data %>%
  filter(Compound == "DMSO")

mercury_compounds = c("PHENYLMERCURIC ACETATE", "THIMEROSAL")

mass_info <- library_data %>%
  filter(`Chemical name` %in% round3_OD750_compounds) %>%
  mutate(mass_mg = MolWt*(1.667*10^-6)*1000)
mass_info

mercury_info <- library_data %>%
  filter(`Chemical name` %in% mercury_compounds) %>%
  mutate(mercury_mass = 200.59*(1.667*10^-6)*1000,
         fold_over_drinking = mercury_mass / 0.001)
mercury_info
```

```{r round3_OD750}
round3_figA1 <- round3_OD_data %>%
  filter(timepoint == "T2") %>%
  filter(well_type == "Experimental") %>%
  select(Compound, Concentration, OD) %>%
  filter(Compound %in% round3_OD750_compounds) %>%
  pivot_wider(names_from = "Concentration", values_from = "OD") %>%
  mutate(`0` = median(round3_OD_control_data$OD)) %>%
  pivot_longer(-Compound, names_to = "Concentration", values_to = "OD") %>%
  mutate(Concentration = signif(as.numeric(Concentration), 2)) %>%
  left_join(round3_OD750_compounds_df, by = "Compound") %>%
  mutate(hit_type_order = case_when(hit_type == "lower" ~ 2,
                                    hit_type == "higher" ~ 1),
         hit_type_name = case_when(hit_type == "lower" ~ "Decrease",
                                   hit_type == "higher" ~ "Increase")) %>%
  mutate(Compound = str_to_title(Compound)) %>%
  mutate(Compound = case_when(Compound == "Methyl 7-Deshydroxypyrogallin-4-Carboxylate" ~ "Methyl 7-Deshydroxy- pyrogallin-4-Carboxylate",
                              Compound == "Dl-Alpha-Methyl-P-Tyrosine" ~ "Dl-Alpha-Methyl- P-Tyrosine",
                              TRUE ~ Compound)) %>%
  filter(hit_type_name == "Increase") %>%
  ggplot() +
  geom_line(aes(x = Concentration, y = OD, colour = Compound), show.legend = FALSE) + 
  geom_point(aes(x = Concentration, y = OD), show.legend = FALSE) +
  facet_wrap(~Compound, 
             labeller = labeller(Compound = label_wrap_gen(width = 21)), ncol = 3) +
  labs(y = bquote(OD[750]), x = expression(paste("Concentration (", mu, "M)"))) +
  scale_colour_manual(values = c("#B35806", "#E48B21", "#EBDCD0", "#887CB2", "#542788", "black"))
round3_figA1

round3_figA2 <- round3_OD_data %>%
  filter(timepoint == "T2") %>%
  filter(well_type == "Experimental") %>%
  select(Compound, Concentration, OD) %>%
  filter(Compound %in% round3_OD750_compounds) %>%
  pivot_wider(names_from = "Concentration", values_from = "OD") %>%
  mutate(`0` = median(round3_OD_control_data$OD)) %>%
  pivot_longer(-Compound, names_to = "Concentration", values_to = "OD") %>%
  mutate(Concentration = signif(as.numeric(Concentration), 2)) %>%
  left_join(round3_OD750_compounds_df, by = "Compound") %>%
  mutate(hit_type_order = case_when(hit_type == "lower" ~ 2,
                                    hit_type == "higher" ~ 1),
         hit_type_name = case_when(hit_type == "lower" ~ "Decrease",
                                   hit_type == "higher" ~ "Increase")) %>%
  mutate(Compound = str_to_title(Compound)) %>%
  mutate(Compound = case_when(Compound == "Methyl 7-Deshydroxypyrogallin-4-Carboxylate" ~ "Methyl 7-Deshydroxy- pyrogallin-4-Carboxylate",
                              Compound == "Dl-Alpha-Methyl-P-Tyrosine" ~ "Dl-Alpha-Methyl- P-Tyrosine",
                              TRUE ~ Compound)) %>%
  filter(hit_type_name != "Increase") %>%
  filter(Compound != "Riboflavine") %>%
  ggplot() +
  geom_line(aes(x = Concentration, y = OD, colour = Compound), show.legend = FALSE) + 
  geom_point(aes(x = Concentration, y = OD), show.legend = FALSE) +
  facet_wrap(~Compound, 
             labeller = labeller(Compound = label_wrap_gen(width = 21)), ncol = 3) +
  labs(y = bquote(OD[750]), x = expression(paste("Concentration (", mu, "M)"))) +
  scale_colour_manual(values = c("#FDC57E", "#BEBADA", "black", "black", "black", "black", "black"))
round3_figA2

round3_od_panels <- plot_grid(round3_figA1, round3_figA2, 
                  ncol = 1,
                  labels = c("G", "H"),
                  label_size = 14,
                  rel_heights = c(2,3))
round3_od_panels
```

```{r round2-3_fig}
round12 <- plot_grid(od_panels, round2_od_panels,
          ncol = 1,
          labels = c("", ""),
          label_size = 14, 
          rel_heights = c(3,3))
round12

round123 <- plot_grid(round12, round3_od_panels,
          ncol = 2,
          labels = c("", ""),
          label_size = 14, 
          rel_widths = c(5,3))
round123
```

\newpage

### Bioactive screen - Hit Validation
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

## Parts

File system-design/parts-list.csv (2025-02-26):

Part Name | Manufacturer* | Retailer | Cost Per Unit | Current Rating | Voltage Rating | Key Specifications | Purpose | Verified URL
384-LED Array | Guangzhou Juhong Optoelectronics Co., Ltd. | - | $68.50 USD | 150 mA | 48 V | 5000K light temp, 40-60°C optimal temp range, superconducting aluminum | Provide light to microplate wells | -
3D Printed LightBox | - | - | - | - | - | 18mm H x 85.47mm W x 121.09mm L, ~5mm LED-to-plate distance | Hold LED array and align with microplate | -
3D Printed Connector Piece | - | - | - | - | - | Connects slip ring to fan | Mount slip ring to fan | -
Banana Jack to Spade Lug (Red) | Mueller Electric Co. | DigiKey | $1.90 | 36 A | 30 VAC/60 VDC | 4mm connectors | Connect LED arrays to terminal strip | https://www.digikey.ca/en/products/detail/mueller-electric-co/BU-30211A-2/5800990
Banana Jack to Spade Lug (Black) | Mueller Electric Co. | DigiKey | $1.90 | 36 A | 30 VAC/60 VDC | 4mm connectors | Connect LED arrays to terminal strip | https://www.digikey.ca/en/products/detail/mueller-electric-co/BU-30211A-0/5800989
12 Position Terminal Strip (25A) | - | Lee's Electronics | $4.69 | 25 A | 600 V | 19mm H x 28mm W x 165mm L | Distribute power to LED arrays | https://leeselectronic.com/en/product/647-terminal-12-position-25a-600v-tb-2512.html
12 Position Terminal Strip (15A) | - | Lee's Electronics | $4.25 | 15 A | 600 V | 18mm H x 22mm W x 126mm L | Distribute power to LED arrays | https://leeselectronic.com/en/product/650-terminal-12-position-15a-tb-1512.html
Terminal Bus (15A) Red | - | Lee's Electronics | $2.75 | 15 A | - | - | Connect terminal strip positions | https://leeselectronic.com/en/product/3032-terminal-bus-small-12-pin-red.html
Terminal Bus (15A) Black | - | Lee's Electronics | $2.75 | 15 A | - | - | Connect terminal strip positions | https://leeselectronic.com/en/product/3030-terminal-bus-small-12-pin-black.html
18 AWG Wire | Penn Elcom | - | $1.55/m | 4.2 A | 300 V | 18 AWG flat cable | Connect system components | https://www.pennelcomonline.com/us/Penn-Elcom-Led-2-Core-Flat-Cable-18awg-Stranded-Copper-CA2F18/m-9714.aspx
Luminaire Wire Connector | Ideal | Home Depot | $10.27/5-pack | - | 600 V | Two-pole connector | Connect wires | https://www.homedepot.ca/product/ideal-luminaire-disconnect-5-pack-/1000511513
Crimp-free Butt Splice | Ideal | Home Depot | $5.86/10-pack | - | 600 V | For stranded/solid core wires | Connect wires | https://www.homedepot.ca/product/ideal-crimp-free-butt-splice-10-pack-/1000663495
Slip Ring | SparkFun | - | $29.95 | 10:00 AM | 380 VDC/AC | 3 wires, 16 AWG, 250 RPM, IP51 | Allow 360 degree rotation with electrical connection | https://www.sparkfun.com/products/13063
Machine Screws (M5) | Paulin | Home Depot | $0.36 + $0.19 | - | - | M5 diameter, 16mm length | Attach slip ring to connector piece | https://www.homedepot.ca/product/paulin-m5-80-x-16mm-class-8-8-metric-hex-cap-screw-din-933-zinc-plated/1000128423
Machine Screws (6-32) | Paulin | Home Depot | $0.16 + $0.18 | - | - | 6-32 diameter, 1 inch length | Attach terminal strips to stackers | https://www.homedepot.ca/product/paulin-6-32-x-1-inch-round-head-slot-machine-screw-solid-brass/1000128179
MeanWell LED Driver | Mean Well USA Inc. | DigiKey | $48.67 | 2.5 A | 48 V | 120W, IP67, 90-305 VAC input | Power source for LED arrays | https://www.digikey.ca/en/products/detail/mean-well-usa-inc/PWM-120-48/7705925
Arduino Uno | Arduino | - | $29.47 | - | 5 V operating | 14 digital I/O, 6 PWM pins | Control LED array current | https://store.arduino.cc/usa/arduino-uno-rev3
12V Power Supply | TMEZON | Amazon | $13.99 | 2:00 AM | 12 V | 100-240V AC input, 2.1mm plug | Power dimming circuit | https://www.amazon.ca/TMEZON-Power-Adapter-Supply-2-1mm/dp/B00Q2E5IXW
Barrel Jack Breakout | Dale Wheat | - | $3.00 | - | - | 2.1mm version | Connect power supply to circuit | https://www.dalewheat.com/product/barrel-jack-breakout-board-kit/
1kOhm Resistor | - | Lee's Electronics | - | - | - | 1/8W 1kOhm | PWM current control (diming circuit) | https://leeselectronic.com/en/product/95116-resistor-1-8w-1kohm-5-10pcs.html
NPN Transistor | - | Lee's Electronics | - | - | - | 2N3904 | PWM current control (diming circuit) | https://leeselectronic.com/en/product/7178-7178TRANSISTOR2N3904NPN5PCS.html
PNP Transistor | - | Lee's Electronics | - | - | - | 2N3906 | PWM current control (diming circuit) | https://leeselectronic.com/en/product/7175-7175TRANSISTOR2N3906PNP5PCSPKG.html
Perma-Proto Board | Adafruit | Adafruit | - | - | - | Quarter-sized breadboard | Mount dimming circuit components | https://www.adafruit.com/product/1608

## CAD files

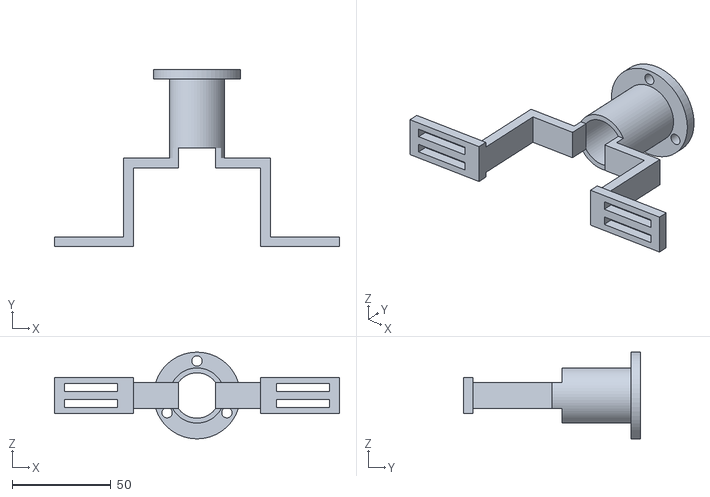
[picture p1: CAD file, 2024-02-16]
system-design/models/slipring_connector.stl
144.6 x 90.0 x 44.0

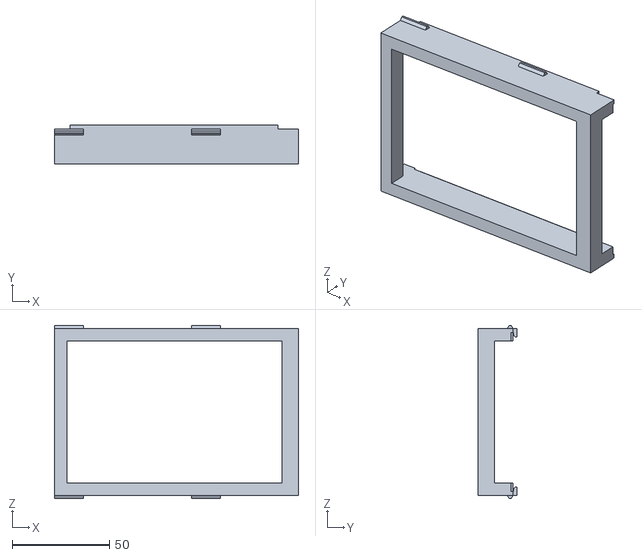
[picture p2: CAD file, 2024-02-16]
system-design/models/LED_array_support.stl
125.5 x 20.0 x 89.0

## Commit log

2024-02-14 Initial data upload
    [2973_BG11_plate_layout.csv, 2973_BG11_plate_metadata.csv, 2973_seal_growth_data.csv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]
2024-02-14 Add models in .stl format
2024-02-16 Model upload
    [LED_array_support.stl, slipring_connector.stl]
2024-11-08 Add evaporation experiment data and plots
    [echo_evaporation_data.csv]
2025-02-26 Update for publication
    [BG11_opt_OD_data.csv, LED_array_support.stl, bioactive_screen_round3_OD_data.csv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]
